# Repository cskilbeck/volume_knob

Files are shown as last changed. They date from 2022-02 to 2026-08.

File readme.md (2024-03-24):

# Tiny Little USB Knob

It sends HID or MIDI messages to the host device when you turn or click the knob.

Instructions for flashing new HID firmware are [here](https://skilbeck.com/tiny-usb-knob/tiny-usb-knob)

Instructions for flashing new MIDI firmware are [here](https://skilbeck.com/tiny-usb-knob/tiny-usb-midi-knob)

Configurator for the HID version is [here](https://hid.skilbeck.com)

Configurator for the MIDI version is [here](https://midi.skilbeck.com)

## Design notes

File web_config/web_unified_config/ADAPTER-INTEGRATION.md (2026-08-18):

# Adding the TRS MIDI adapter to the unified configurator

The `midi_adapter` project (`E:\dev\midi_adapter`) is a TRS-to-USB MIDI device that speaks
the same SysEx protocol as the Tiny MIDI Knob. It should appear in this configurator
alongside the knob and the HID keyboards rather than getting an app of its own.

Its firmware plan and the protocol details are in `midi_adapter/firmware/FIRMWARE-PLAN.md`;
the wire format is deliberately identical to the knob's.

## What the adapter is

TRS jack in, USB MIDI out. Three explicit modes — MIDI passthrough, expression pedal,
footswitch — chosen by the user, with **no auto-detection** (the reasoning is in the
firmware plan: an open footswitch is electrically identical to an empty jack, so detection
cannot be complete, and both non-MIDI modes need a calibration step from the user anyway).

Differences from the knob that matter here:

| | Knob | Adapter |
|---|---|---|
| model number | `0x3322` | `0x3323` |
| config device-type nibble | `0x0` | `0x1` |
| config length | 26 bytes | 32 bytes |
| SysEx `0x05` (bootloader) | supported | **not implemented** — the CH32V203 has no software path to its bootloader. Do not offer a firmware-update button for this device. |
| SysEx `0x06` (probe) | — | returns four raw ADC readings, for a future calibration UI |

## What is in the way

Three things in `Midi.js` are hardcoded to the knob:

1. `MIDI_MODEL_NUMBER_LOW/HIGH` — `on_device_id_response()` compares against them and
   returns early otherwise, so the adapter is currently invisible.
2. `CONFIG_LEN`, `config_map`, `default_config`, `flags`, `is_supported_config_version` —
   module-level, closed over by `config_from_bytes()` and `bytes_from_config()`.
3. `DeviceList.vue` renders `<MidiDevice>` for every MIDI device with no dispatch.

Plus: `on_midi_message()` routes only `0xB0` control change to devices. The adapter passes
through arbitrary MIDI, so the monitor needs a general hook.

## Plan

### 1. Device-type registry in `Midi.js`

A table keyed by model number holding what differs — model, config length, config map,
defaults, flags, and which component renders it. `on_device_id_response()` keeps checking
manufacturer and family, then *looks the model up* instead of comparing it, and stores the
entry as `device.type`. Unknown models are ignored and logged, as now.

`config_from_bytes()` and `bytes_from_config()` take the type as a parameter defaulting to
the knob, so existing call sites are untouched.

**The knob's tables deliberately stay in `Midi.js` for now** rather than moving to
per-device modules. This step is the only one that can break shipped hardware, so it is
kept to the smallest diff that works; `midi.default_config` and `midi.flags` continue to
export the knob's values so `MidiDevice.vue` needs no changes at all. That shim is
temporary — new code should read `device.type.*`.

**Verify the knob still enumerates and configures before going further.**

### 2. Adapter entry

Model `0x3323`, 32-byte config map. The map is already written and proven against real
hardware in `midi_adapter/web_test/index.html` — copy it from there rather than
re-deriving it from the C struct.

The struct is `__attribute__((packed))` and carries a `_Static_assert` on its size, because
without packing GCC puts a hole at offset 5 and the map silently decodes one byte out from
there on. A size assert cannot catch a *reordering*, so if `config.h` changes, this map
changes with it.

### 3. Dispatch in `DeviceList.vue`

Same shape as the existing HID dispatch: a name-to-component map, `:is` on the resolved
component, skip if unknown.

### 4. `MidiAdapterDevice.vue` — first cut, deliberately incomplete

- header: name, firmware version, connect toggle (patterns lifted from `MidiDevice.vue`)
- **mode selector** — passthrough / expression / switch — and save
- **MIDI monitor** — decoder already written in `midi_adapter/web_test/index.html`

Deferred: CC number and channel, ranges, direction, flags, thresholds, and the calibration
wizard built on SysEx `0x06`. The full 32-byte config still round-trips intact, because it
is read, one field is edited, and the whole thing is written back.

### 5. General MIDI hook

Route non-SysEx messages to `device.on_midi_in?.(data)` alongside the existing
`on_control_change` path. Additive; the knob is unaffected.

### 6. Dummy adapter

`make_dummy_midi_ports()` is already dependency-injected, so it takes a device type rather
than the knob's constants. Gives a "Demo TRS MIDI Adapter" for UI work with no hardware
attached, exactly as the demo knob does today.

## Later

- **Calibration wizard** on SysEx `0x06`: poll at ~20Hz, show live TIP and RING bars, ask
  the user to sweep the pedal. Whichever bar moves sets the wiper-on-ring flag and its
  extremes capture the input range. This is what replaces auto-detection, and it is better
  than firmware guessing precisely because the browser can ask a question and show a
  result.
- **Port naming.** The adapter's USB-MIDI jack descriptors carry no strings, so the host
  names its ports numerically. Either add string descriptors in firmware or lean on the
  existing localStorage rename in the device header.

## Two devices of the same name (done, 2026-08-15)

Two adapters both report their MIDI port as `midi_adapter`, and four things keyed on that
name: `device_from_input_port()` (which routes the monitor and every CC), the `'connected'`
branch of `on_state_change`, the reuse map in `init_devices()`, and `DeviceList.vue`'s
`:key`. The failure is quiet and confusing — one adapter's traffic draws on the other's
panel, and the second panel looks dead. Two knobs had the same fault; it was never
adapter-specific.

**Run-time identity is now `device.key`, the output port's id.** `device.input_id` is kept
separately because an input's id differs from its output's, and it is deliberately *not*
cleared on disconnect: it is the only way to recognise the port when it returns. The
reconnect path falls back to a name match restricted to devices with no port of that type
bound, which stays unambiguous among duplicates and preserves the old behaviour on a host
that renumbers ids across a replug.

**Persistent identity is the serial number**, which the adapter now appends to its identity
reply (`midi_adapter/firmware/FIRMWARE-PLAN.md` §4). Port ids are unique but not durable,
so per-unit labels in localStorage hang off the serial. Devices without one — the knob —
keep the old name-keyed label, so existing stored labels survive.

Demo port ids are qualified by name for the same reason: they were both hardcoded
`demo-midi-in` / `demo-midi-out` and would have collided under id-keying.

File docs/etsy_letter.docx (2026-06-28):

Here is your Tiny USB Volume Knob

Instructions

1. Plug it in using a USB cable.
2. Your computer should recognize it as ‘Tiny USB Knob’.
3. Twist the knob to change the audio volume.
4. Click the knob to mute/unmute your audio.

NOTE! READ THIS:

If it doesn’t work but flashes slowly after you’ve plugged it in, the USB connection failed – maybe the USB cable is a ‘Charger Only’ cable. Use a data-enabled cable! If you suspect the cable, try another device with it. If that also doesn’t work, try another cable.

Configuration

To change the HID codes that are sent when the knob is turned or clicked, point your Chrome browser at usbknob.com (https://hid.skilbeck.com) and click ‘Scan’ while your Tiny USB Knob is plugged in. Other browsers not supported, I’m afraid.

Discord

For help on Discord, search for the ‘Tiny USB Knob’ channel.

Advanced

To flash new firmware, click and hold the knob while you plug in the device. Once in flashing mode, you’ll have to either flash it with new firmware or unplug and plug it back in to get it back to normal mode.

`

IMPORTANT INSTRUCTIONS!

IMPORTANT INSTRUCTIONS!

IMPORTANT INSTRUCTIONS!

IMPORTANT INSTRUCTIONS!

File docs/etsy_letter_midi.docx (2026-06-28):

Here is your Tiny USB MIDI Knob

Instructions

1. Plug it in using a USB cable.
2. Your computer should recognize it as a device called ‘Tiny USB Knob’.
3. Turn and click the knob to send Continuous Control MIDI notifications.

Please read this!

If your Tiny USB MIDI Knob doesn’t work but flashes slowly after you’ve plugged it in, that means the USB connection failed. Maybe the USB cable is a ‘Charger Only’ cable without data lines. Use a data-enabled cable! If you suspect the cable, try another device with it. If that also doesn’t work, it’s time to find another cable.

Discord

To get help from me and other users on Discord, search for the ‘Tiny USB Knob’ channel

Configuration

If you want to change the CC values that are sent when the knob is turned or clicked, point your browser at usbknob.com (https://midi.skilbeck.com). It should pick up the device automatically,

But if it doesn’t try clicking ‘Scan’ while your Tiny USB MIDI Knob is plugged in. Safari is not supported.

Advanced users

If you want to flash new firmware, click and hold the knob while you plug in the device. Once in flashing mode, you’ll have to either flash it with new firmware or unplug and plug it back in to get it back to normal mode.

Important Instructions!

Important Instructions!

Important Instructions!

Important Instructions!

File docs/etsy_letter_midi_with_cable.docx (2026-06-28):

# Here is your Tiny USB MIDI Knob

Instructions

1. Plug it in using the supplied Micro-USB cable.
2. Your computer should recognize it as ‘Tiny USB Knob’.
3. Click and Twist the knob to send Continuous Control MIDI notifications.

Pro tip

If you want to change the CC values that are sent when the knob is turned or clicked, point your browser at usbknob.com. It should pick up the device automatically, but if it doesn’t try clicking ‘Scan’ while your Tiny USB MIDI Knob is plugged in. Safari is not supported.

Advanced users

If you want to flash new firmware, click and hold the knob while you plug in the device. Once in flashing mode, you’ll have to either flash it with new firmware or unplug and plug it back in to get it back to normal mode.

Support

Look for the “Tiny USB Knob” channel on Discord.

Important
Instructions

Important
Instructions

Important
Instructions

Important
Instructions

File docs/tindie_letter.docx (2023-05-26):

Hi,

Thanks so much for ordering a Tiny USB Volume Knob! I hope you get as much use out of it as I do.

Instructions

1. Plug it in using a Micro-USB cable
2. Your computer should recognize it as a device called ‘VOLUME KNOB’
3. Twist the knob to change the audio volume
4. Click the knob to mute your audio

NOTE

Please read this: If your Tiny USB Volume Knob doesn’t work but flashes slowly after you’ve plugged it in, that means the USB connection failed. This is because your USB cable is a ‘Charger Only’ cable without data lines. Please use a data-enabled cable! If you suspect the cable, try another device with it to test it. If that also doesn’t work, it’s time to find another cable.

Pro tip

If you want to change the direction (i.e. clockwise to decrease volume), triple click the knob. Triple click again to change it back.

Advanced users

If you want to flash new firmware, click and hold the knob down for over 5 seconds. Once the device is in flashing mode, you’ll have to either flash it with new firmware or unplug and plug it back in to get it back to normal mode.

And…

Small favour to ask – if you can bear it, would you mind awfully posting a Tweet about it? I don’t have a marketing budget (I don’t have any kind of budget at all, in fact), so getting the word out is kind of a challenge. Every mention helps! This QR code will get you started:

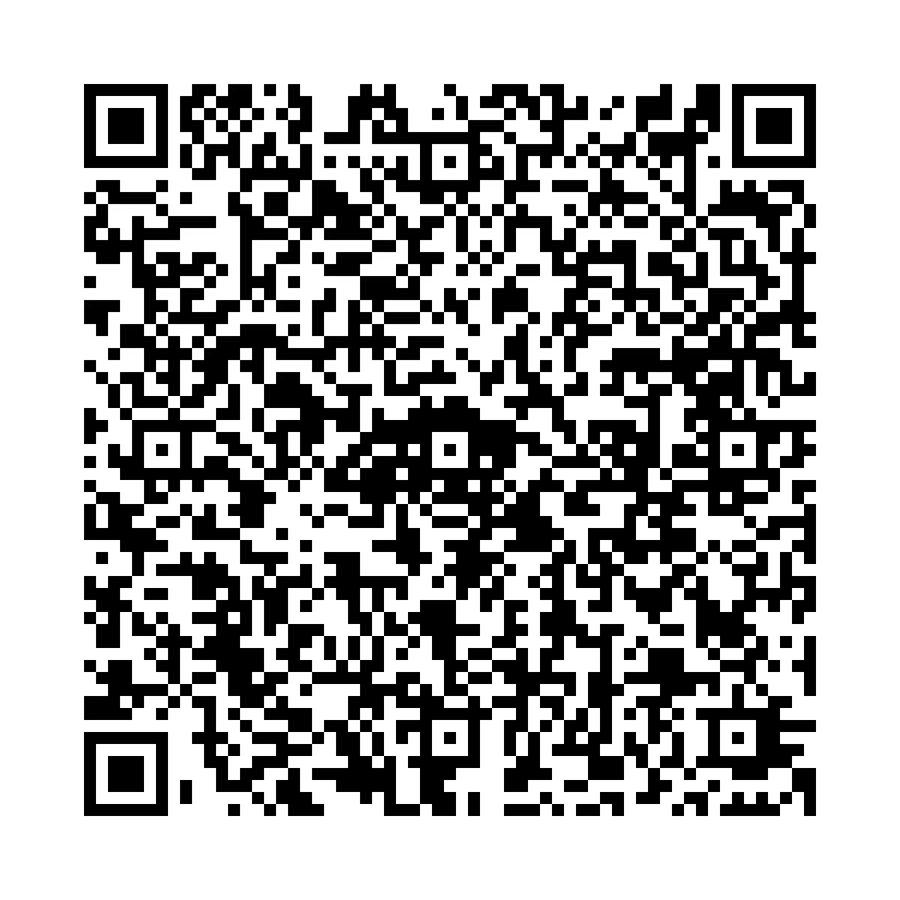
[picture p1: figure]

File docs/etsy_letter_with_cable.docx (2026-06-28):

Here is your Tiny USB Volume Knob

Instructions

1. Plug it in.
2. Your computer should recognize it as ‘Tiny USB Knob’.
3. Twist the knob to change the audio volume.
4. Click the knob to mute/unmute your audio.

Configuration

To change the HID codes that are sent when the knob is turned or clicked, point your Chrome browser at usbknob.com and click ‘Scan’ while your Tiny USB Knob is plugged in. Other browsers not supported, I’m afraid.

Discord Support

Seach for the Tiny USB Knob channel on Discord for help

Advanced

To put the device in ‘firmware flashing mode’, click and hold the knob while you plug in the device. Once in flashing mode, you’ll have to either flash it with new firmware or unplug and plug it back in to get it back to normal mode.

IMPORTANT
INSTRUCTIONS!

IMPORTANT
INSTRUCTIONS!

IMPORTANT
INSTRUCTIONS!

IMPORTANT
INSTRUCTIONS!

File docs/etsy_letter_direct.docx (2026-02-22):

Tiny USB Volume Knob

Instructions

1. Plug it in
2. Your computer should recognize it as a device called ‘Tiny USB Knob’.
3. Twist the knob to change the audio volume.
4. Click the knob to mute/unmute your audio.

Get Help on Discord

Get help on Discord! Search for the “Tiny USB Knob” channel.

Configuration

To change the keys that are sent when the knob is turned or clicked, point your browser (NOT Safari!) at hid.skilbeck.com and click ‘Scan’ while your Tiny USB Knob is plugged in.

Advanced Users

To flash new firmware, click and hold the knob while you plug in the device. Once in flashing mode, you’ll have to either flash it with new firmware or unplug and plug it back in to get it back to normal mode.

Important
Instructions!

Important
Instructions!

Important
Instructions!

Important
Instructions!

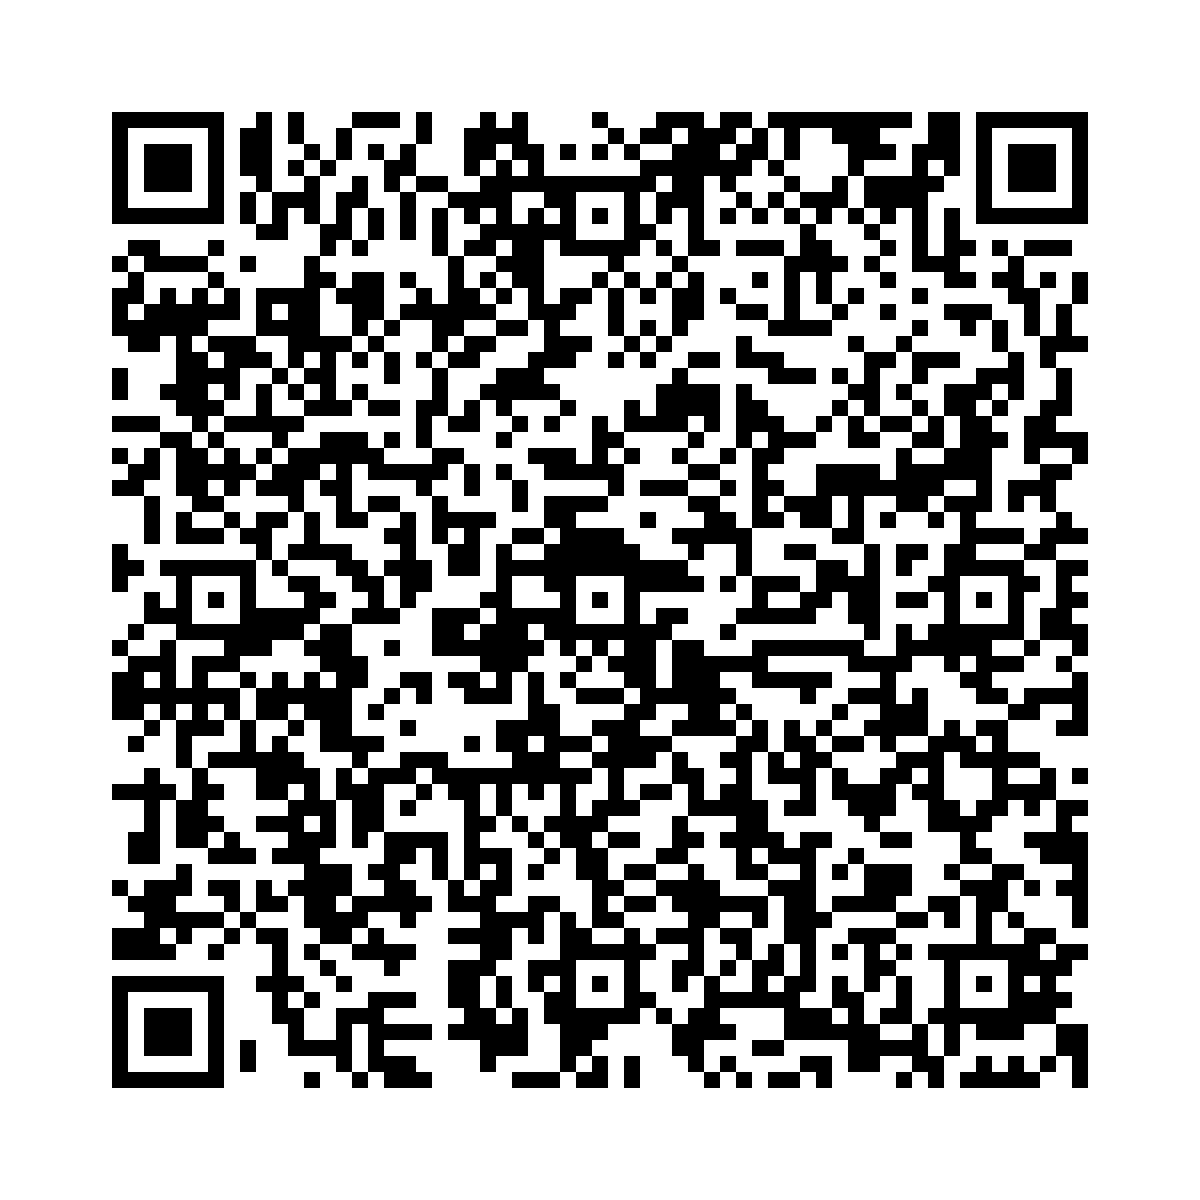
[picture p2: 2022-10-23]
images/qr_etsy.png

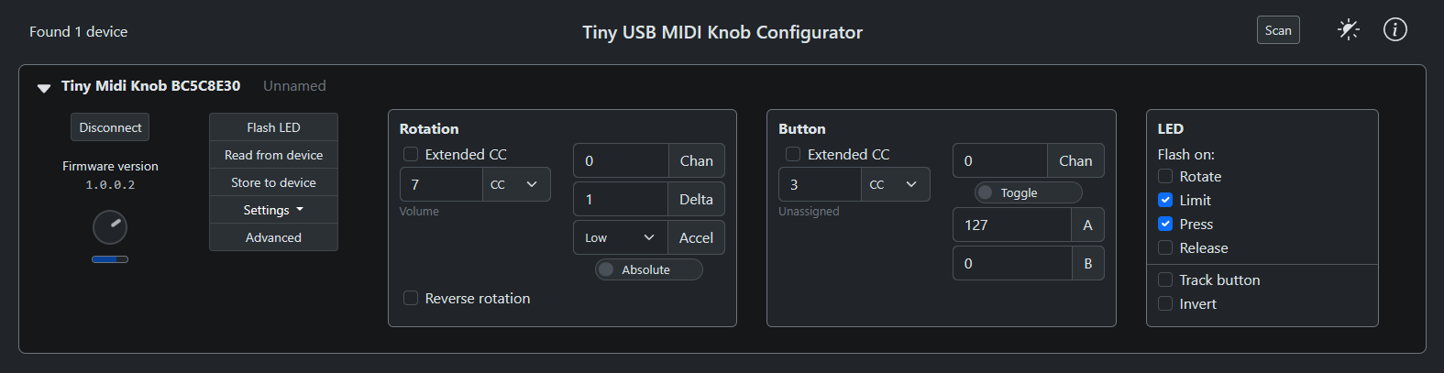
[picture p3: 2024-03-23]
images/midi_configurator_1.png

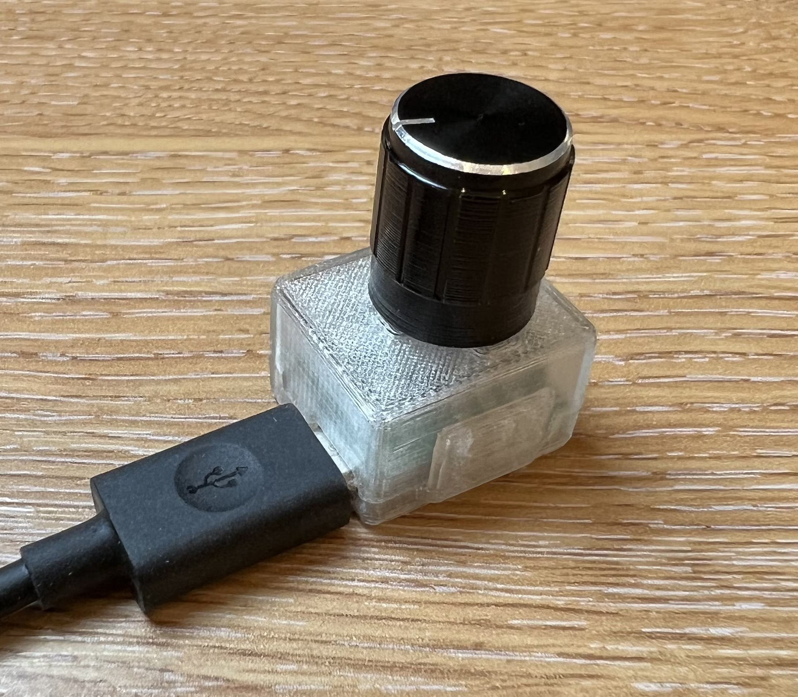
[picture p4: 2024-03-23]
images/tiny_usb_device.jpg

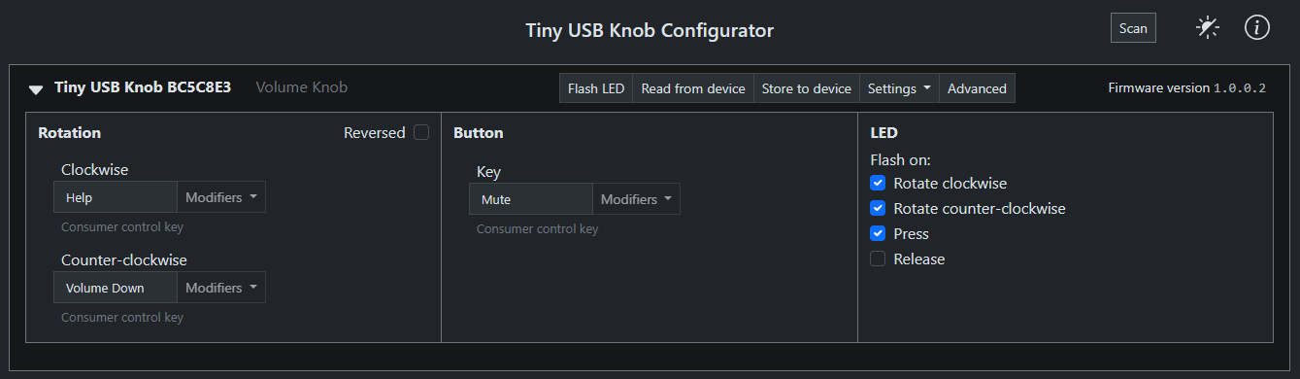
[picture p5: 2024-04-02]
images/hid_configurator_2.png

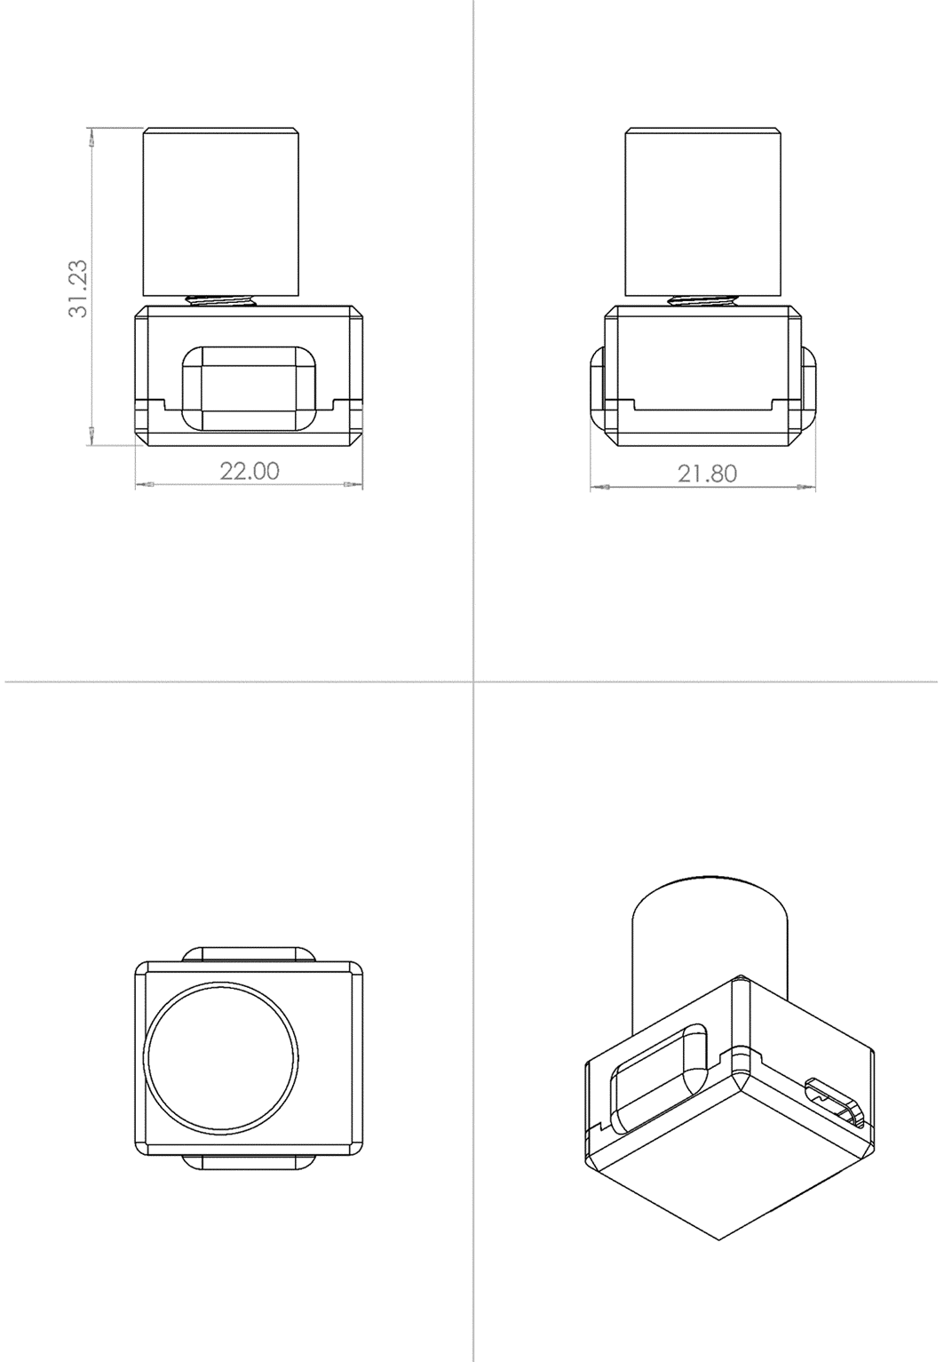
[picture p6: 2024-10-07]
images/dimensions.png

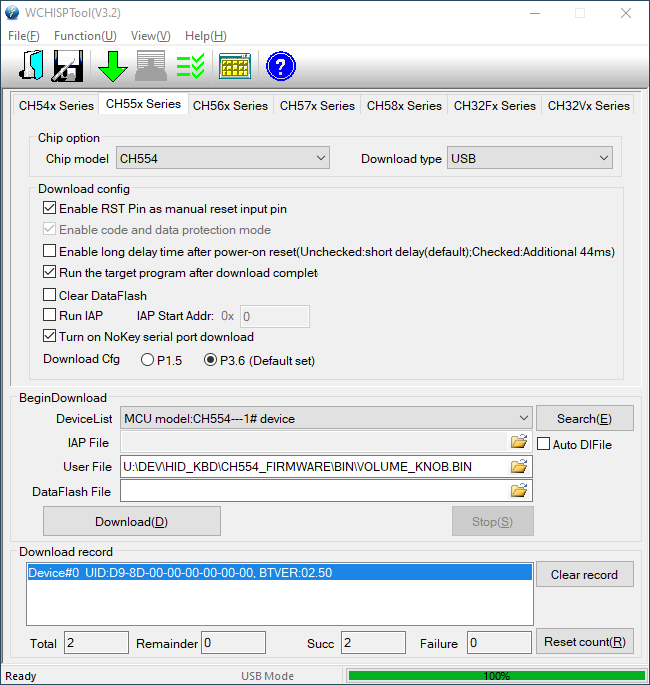
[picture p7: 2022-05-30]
images/wchisp_1.png

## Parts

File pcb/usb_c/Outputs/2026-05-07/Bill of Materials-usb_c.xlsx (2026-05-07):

Designator | Quantity | Comment | Description | Footprint | JLCPCB Part #
C6, C7 | 2 | 1uF | MLCC | MLCC_0603 | C29936
D1 | 1 | 20mA | LED | SMT_LED_0603 | C205445
D6, D7, D8 | 3 | TVS_DIODE | TVS Diode | TVS_DIODE | C151980
F2 | 1 | 1A | Resettable fuse | FUSE 0603_1608 0.5MM | C210357
R1 | 1 | 680r | Resistor | SMT_RES_0603 | C23228
R2, R3 | 2 | 5.1k | Resistor | SMT_RES_0603 | C25804
R6, R7, R8 | 3 | 220r | Resistor | SMT_RES_0603 | C27592
R10 | 1 | 10k | Resistor | SMT_RES_0603 | C25804
U1 | 1 | CH554E | CH554E | MSOP10 | C111293
USB | 1 | USB_C_16_PIN | USB Receptacle TYPE-C 16PIN 2MD | USB_C_16PIN | C2765186

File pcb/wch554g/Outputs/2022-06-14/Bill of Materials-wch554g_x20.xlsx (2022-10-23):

Designator | Quantity | Comment | Description | Footprint | JLCPCB Part #
C6, C7 | 40 | 1uF | MLCC | MLCC 0603 | C105524
C8, C9, C10 | 60 | 6.8nF | MLCC | MLCC 0603 | C1631
D5 | 20 | 20mA | LED | SMT LED 0603 | C138545
D6, D7, D8 | 60 | TVS_DIODE | TVS Diode | SODFL 98x40 2 pin | C384848
F2 | 20 | 1A | FUSE | FUSE_0805 | C70061
MCU2 | 20 | CH554G | CH554G SOP16 MCU | SOP16 x1.27 | C114295
R6, R7, R8 | 60 | 68r | Resistor | 0603 SMT Resistor | C27592
R9 | 20 | 680r | Resistor | 0603 SMT Resistor | C23228
R10 | 20 | 10k | Resistor | 0603 SMT Resistor | C25804
USB | 20 | USB Micro | USB Receptacle | USB Micro B Receptacle | C397452

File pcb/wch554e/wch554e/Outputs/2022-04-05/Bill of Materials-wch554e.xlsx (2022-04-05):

Designator | Quantity | Comment | Description | Footprint | JLCPCB Part #
U1 | 1 |  | CH554E | MSOP10 3x3 x 0.5 | C111293
F1 | 1 | 1A | FUSE | FUSE_0805 | C70061
D4 | 1 |  | LED | SMT LED 0603 | C434424
C1, C2 | 2 | 1uF | MLCC | MLCC 0603 | C105524
C3, C4, C5 | 3 | 10nF | MLCC | MLCC 0603 | C519509
R1, R2, R3 | 3 | 120r | Resistor | 0603 SMT Resistor | C22787
R4 | 1 | 10k | Resistor | 0603 SMT Resistor | C25804
R5 | 1 | 680r | Resistor | 0603 SMT Resistor | C23228
D1, D2, D3 | 3 |  | TVS Diode | SODFL 98x40 2 pin | C384848
J1 | 1 |  | USB Receptacle | USB Micro B Receptacle | C397452

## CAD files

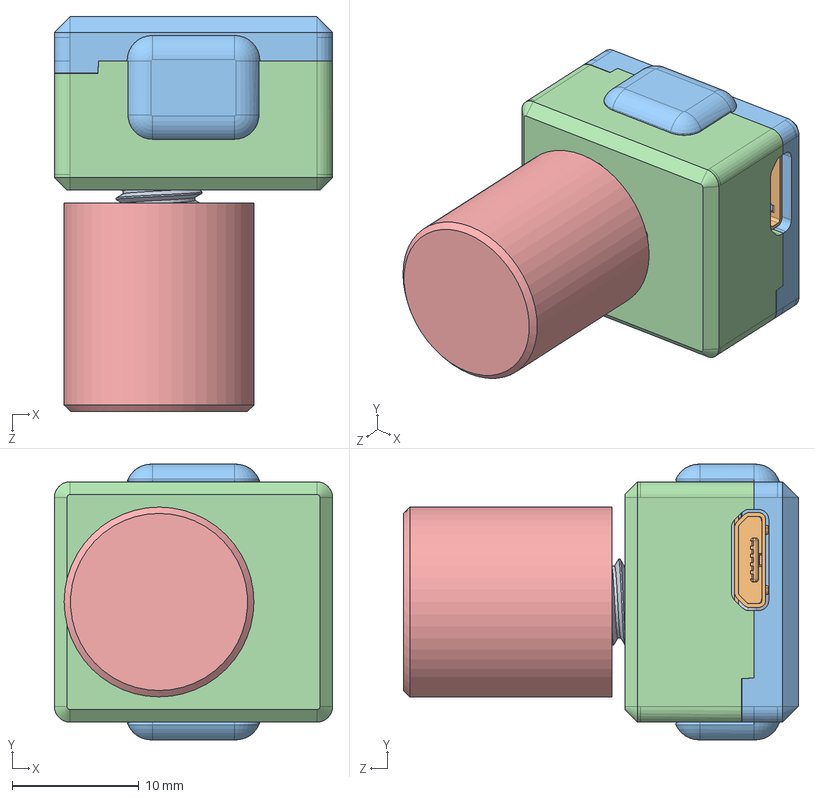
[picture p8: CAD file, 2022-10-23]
enclosure_ch554e_80/enclosure.SLDASM
22.0 x 21.8 x 31.2 mm
pcb
usb_socket
lower
upper
knob

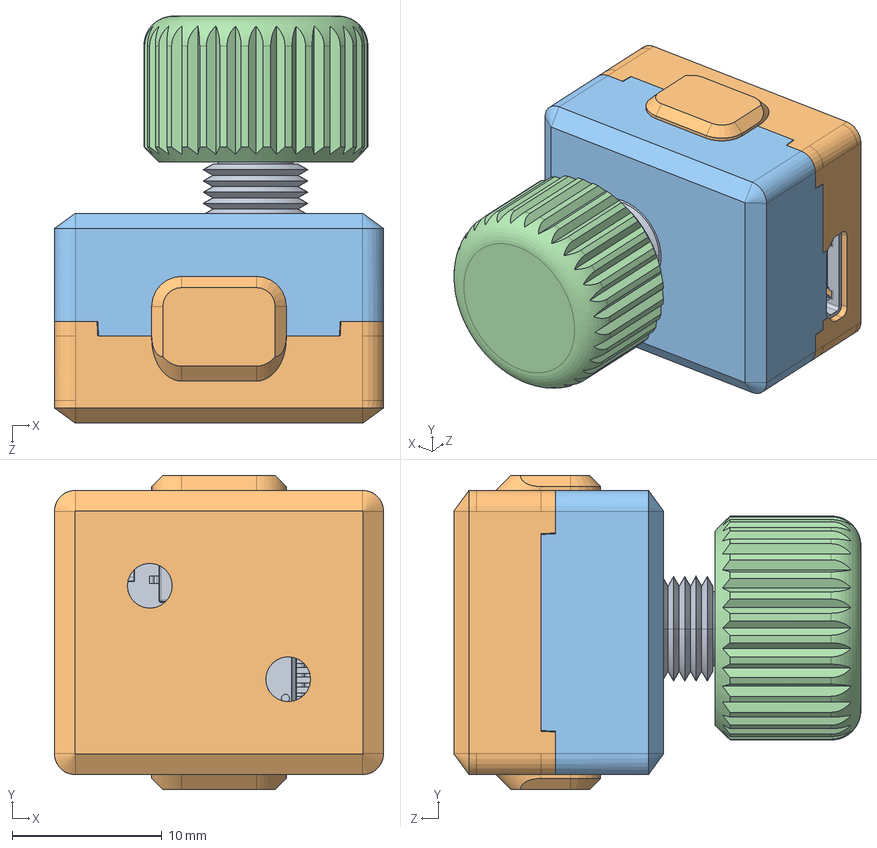
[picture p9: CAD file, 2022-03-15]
enclosures/enclosure16x19/enclosure2.SLDASM
22.0 x 21.0 x 27.2 mm
pcb
lower
upper
knob

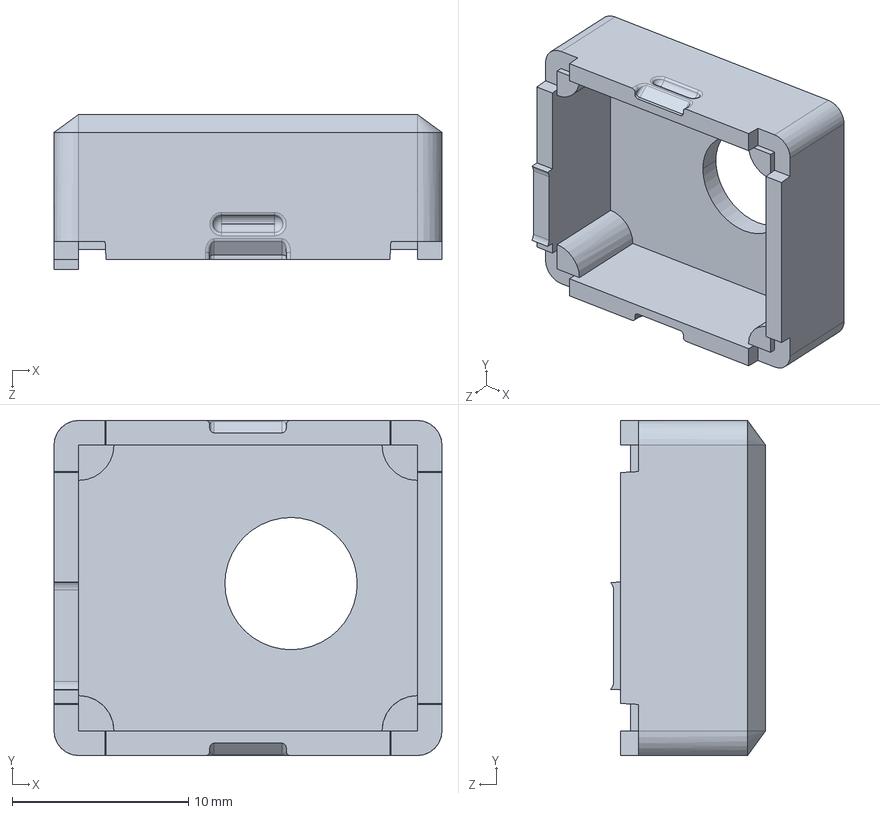
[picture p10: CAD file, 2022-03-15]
enclosures/enclosure16x19/upper.SLDPRT
22.0 x 19.0 x 8.76 mm

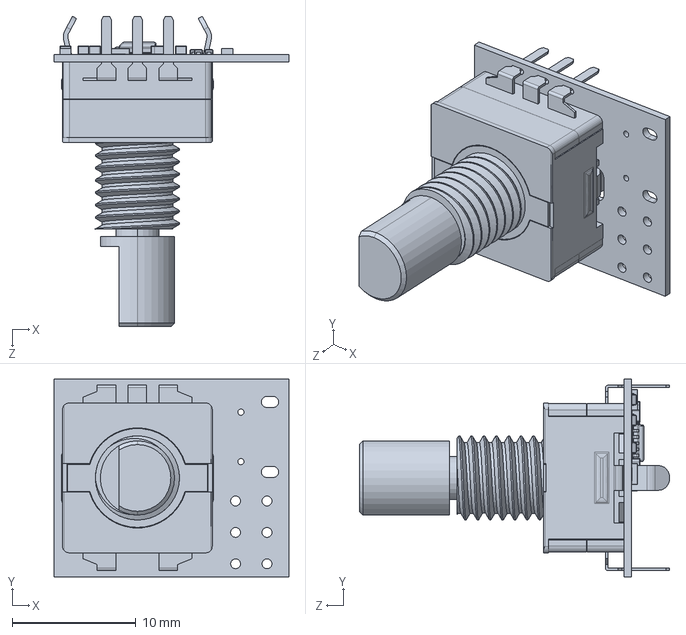
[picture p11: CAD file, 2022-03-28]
enclosures/enclosure_ch554e/pcb_ch554e.SLDPRT
19.0 x 16.0 x 25.1 mm

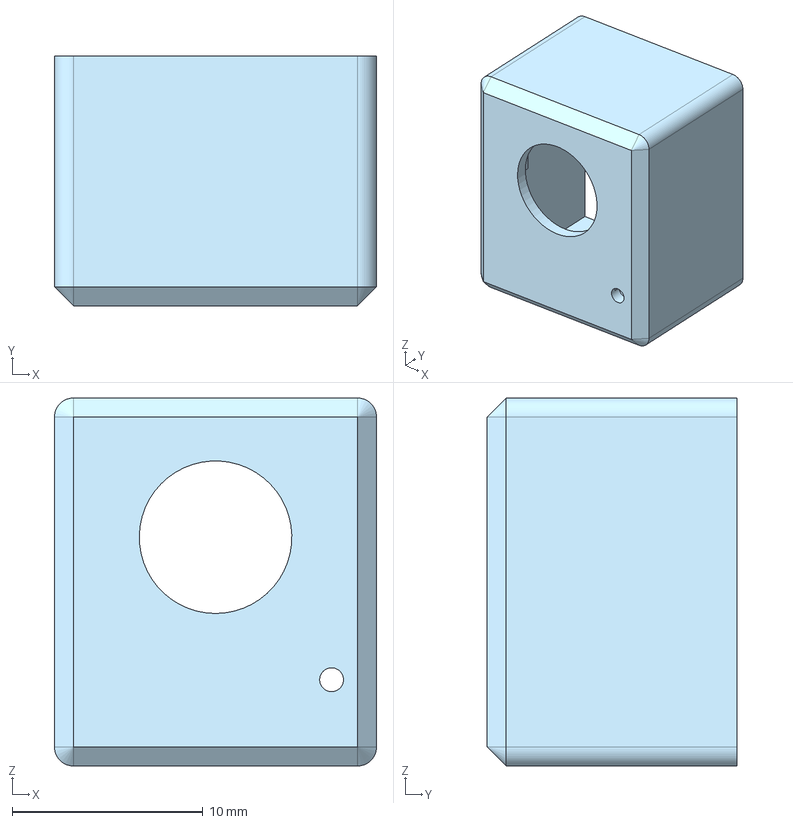
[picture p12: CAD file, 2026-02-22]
enclosures/VK_D1.step
16.9 x 13.1 x 19.3 mm

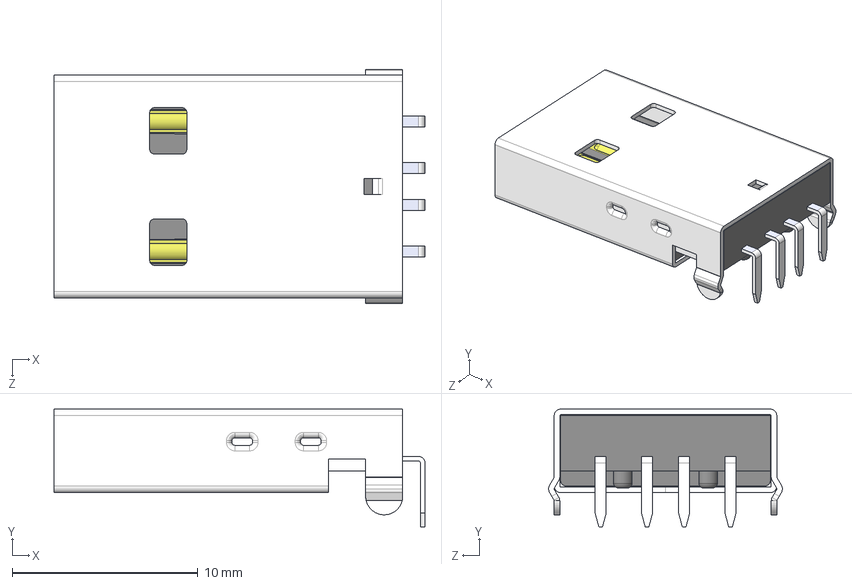
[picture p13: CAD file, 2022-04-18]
pcb/CUI_DEVICES_UP2-AH-1-TH.step
20.0 x 6.35 x 12.6 mm

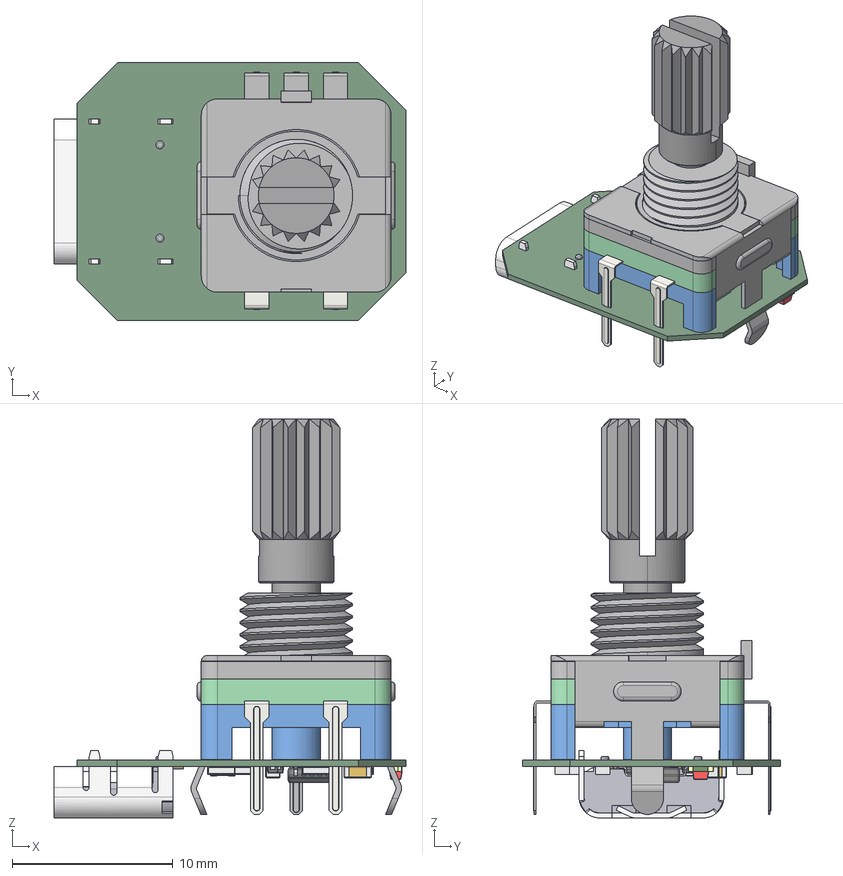
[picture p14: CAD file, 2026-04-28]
pcb/usb_c/Outputs/2026-04-28/usb_c.step
21.9 x 16.0 x 24.8 mm
FUSE 0603_1608 0.5MM
Mid_Body x 7
Mark x 7
tongue
shield
contact_001
contact_002
contact_003
contact_004
contact_court_001
contact_court_002
contact_court_003
contact_court_004
contact_005
contact_006
contact_007
contact_008
contact_court_005
contact_court_006
contact_court_007
contact_court_008
pin_001
pin_002
pin_003
pin_004
pin_005
pin_006
pin_007
pin_008
pin_009
pin_010
pin_011
pin_012
pin_013
pin_014
pin_015
pin_016
Leader x 10
EC11_Rotary_Encoder_Switched
lead x 6
0603 Chip SMD LED (1.6x0.8mm)_coloured

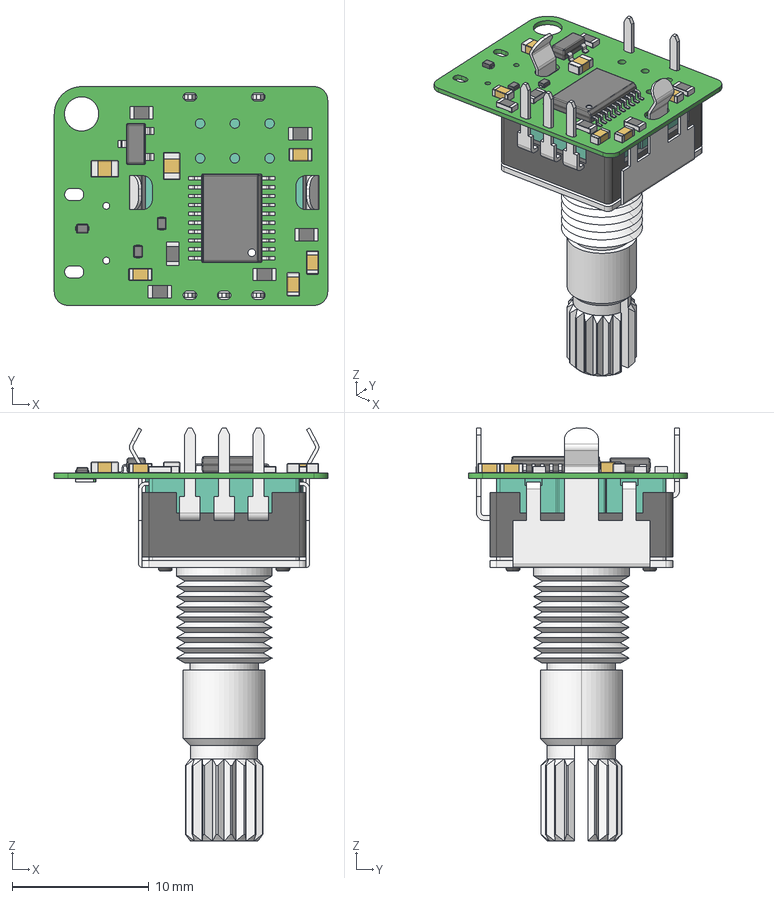
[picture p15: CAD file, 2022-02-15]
pcb/volume_knob/Outputs/2022-02-15/volume_knob.step
20.0 x 16.0 x 30.2 mm
scaled
Open_CASCADE_STEP_translator_6.8_2.1.1 x 3
lead x 6
Mid_Body x 6
Open_CASCADE_STEP_translator_6.8_12.2.1 x 12
Mark x 6
Open_CASCADE_STEP_translator_6.8_14.1
Open_CASCADE_STEP_translator_6.8_14.2.1 x 5
Leader x 23
Open_CASCADE_STEP_translator_6.8_14.1.1 x 4
Open_CASCADE_STEP_translator_6.8_14.1.2 x 4
Open_CASCADE_STEP_translator_6.8_28.1.1 x 2
Open_CASCADE_STEP_translator_6.8_28.1.2 x 2
Open_CASCADE_STEP_translator_6.8_28.2.1 x 2
Open_CASCADE_STEP_translator_6.8_1.1.1

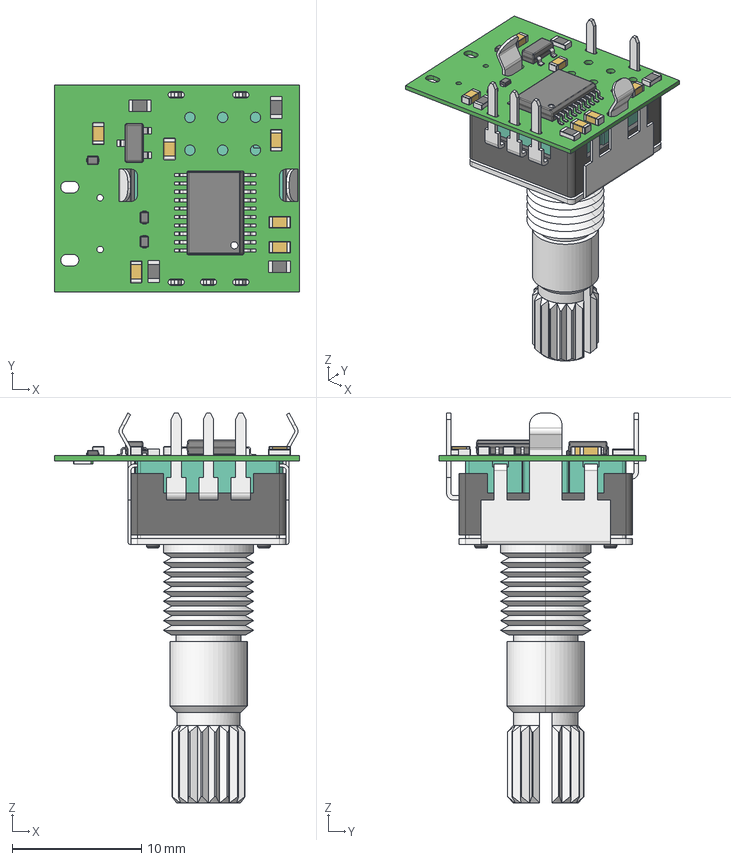
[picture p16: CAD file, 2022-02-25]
pcb/volume_knob/Outputs/2022-02-25/volume_knob.step
19.0 x 16.0 x 30.2 mm
scaled
Open_CASCADE_STEP_translator_6.8_2.1.1 x 3
lead x 6
Mid_Body x 4
Open_CASCADE_STEP_translator_6.8_12.2.1 x 8
Mark x 4
Open_CASCADE_STEP_translator_6.8_14.1
Open_CASCADE_STEP_translator_6.8_14.2.1 x 7
Leader x 23
Open_CASCADE_STEP_translator_6.8_14.1.1 x 6
Open_CASCADE_STEP_translator_6.8_14.1.2 x 6
Open_CASCADE_STEP_translator_6.8_1.1.1

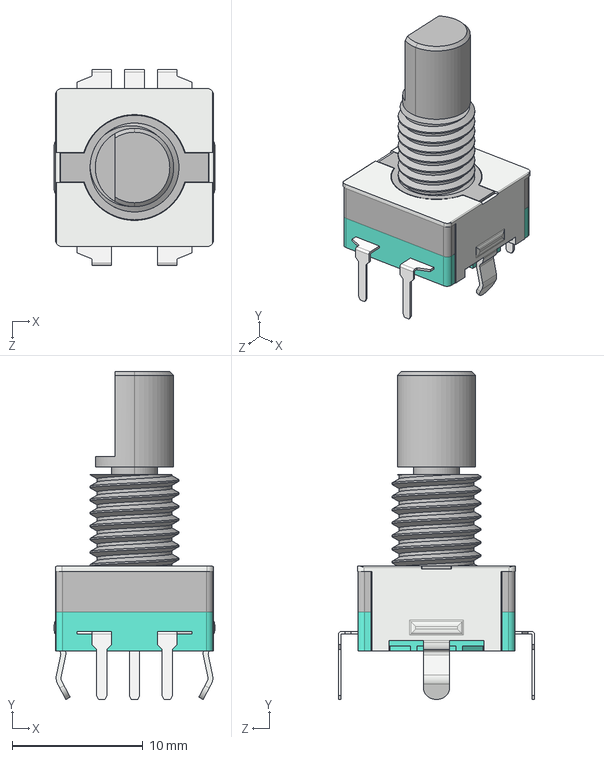
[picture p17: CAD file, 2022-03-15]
pcb/wch554e/wch554e/Models/rotary_encoder.STEP
12.3 x 25.1 x 15.0 mm

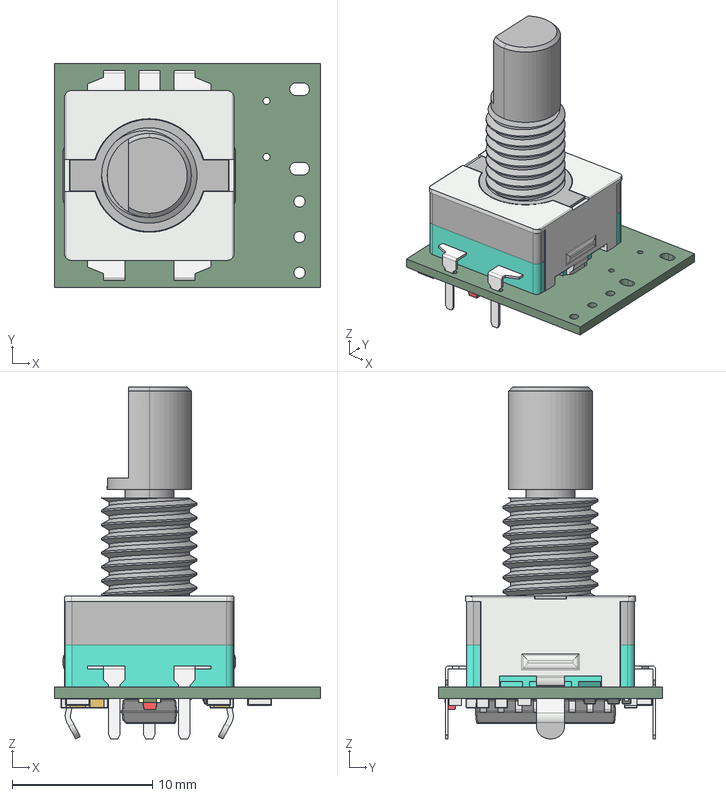
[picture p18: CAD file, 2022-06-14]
pcb/wch554g/Outputs/2022-06-14/wch554g.step
19.0 x 16.0 x 25.1 mm
Open_CASCADE_STEP_translator_6.8_2.1
Open_CASCADE_STEP_translator_6.8_2.2.1
Leader x 16
rotary_encoder
Mid_Body x 5
Open_CASCADE_STEP_translator_6.8_12.2.1 x 10
Mark x 5
Open_CASCADE_STEP_translator_6.8_2.1.1 x 3
lead x 6
0603_Chip_SMD_LED_(1.6x0.8mm)_coloured
Open_CASCADE_STEP_translator_6.8_14.1.1 x 5
Open_CASCADE_STEP_translator_6.8_14.1.2 x 5
Open_CASCADE_STEP_translator_6.8_14.2.1 x 5

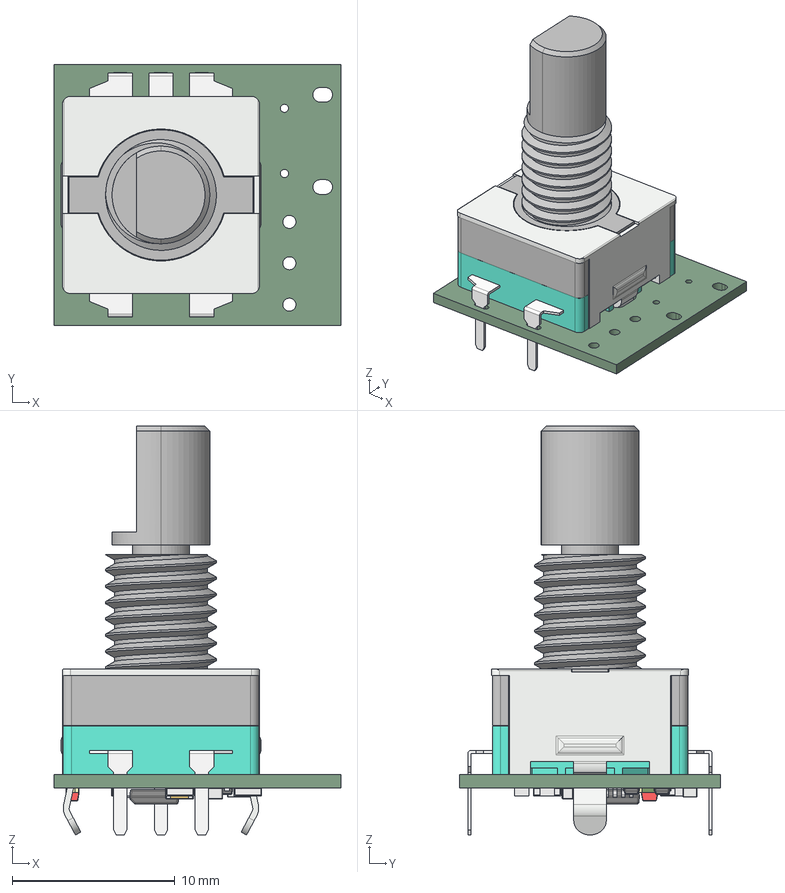
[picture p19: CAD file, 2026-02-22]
pcb/wch554g/Outputs/2025-04-25_V2/wch554g.step
17.6 x 16.0 x 25.1 mm
Mid_Body x 5
Open_CASCADE_STEP_translator_6.8_12.2.1 x 11
Mark x 5
0603_Chip_SMD_LED_(1.6x0.8mm)_coloured
Open_CASCADE_STEP_translator_6.8_12.1
Leader x 10
rotary_encoder
FUSE_0603_1608_0.5MM
Open_CASCADE_STEP_translator_6.8_2.1.1 x 3
lead x 6
Open_CASCADE_STEP_translator_6.8_14.1.1 x 2
Open_CASCADE_STEP_translator_6.8_14.1.2 x 2
Open_CASCADE_STEP_translator_6.8_14.2.1 x 2

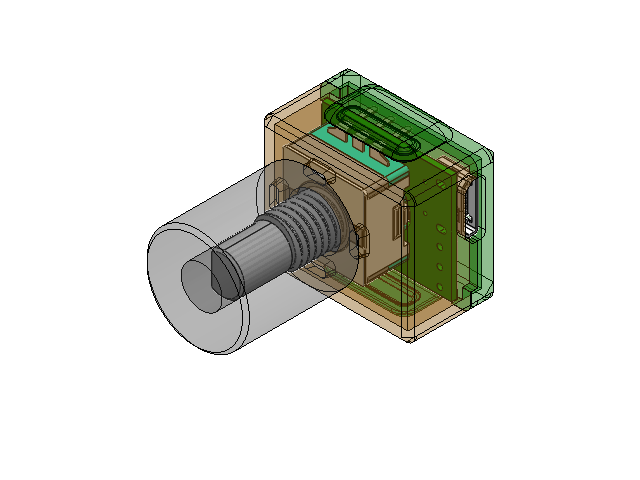
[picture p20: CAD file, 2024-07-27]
enclosures/enclosure_ch554e_80/enclosure.SLDASM
pcb
usb_socket
lower
upper
knob

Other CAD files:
enclosures/enclosure_ch554e_80/pcb.SLDPRT
enclosures/enclosure_V2/knob.SLDPRT
pcb/usb_c/Outputs/2026-05-07/usb_c.step
pcb/wch554e/wch554e/Outputs/2022-04-05/wch554e.step
pcb/wch554g/models/rotary_encoder_1.step.SLDPRT
enclosures/TUVK_Enclosure.step
enclosures/VK_D1.3mf
enclosures/VK_D2.step
enclosures/enclosure/473461001.sldprt
enclosures/enclosure/bottom.SLDPRT
enclosures/enclosure/knob.SLDPRT
enclosures/enclosure/knob.STEP
enclosures/enclosure/lower.STEP
enclosures/enclosure/top.SLDPRT
enclosures/enclosure/upper.STEP
enclosures/enclosure/volume_knob.SLDASM
enclosures/enclosure16x19/encoder.SLDPRT
enclosures/enclosure16x19/encoder2.SLDPRT
enclosures/enclosure16x19/knob.SLDPRT
enclosures/enclosure16x19/lower.SLDPRT
enclosures/enclosure16x19/usb_receptacle.sldprt
enclosures/enclosure_V2/PCB_V2.step
enclosures/enclosure_V2/enclosure_V2.SLDDRW
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

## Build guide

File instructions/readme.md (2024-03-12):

## Tiny USB Midi Knob - Instructions for flashing new firmware

#### 1.  Install <a href="https://www.wch-ic.com/downloads/WCHISPTool_Setup_exe.html" target="_blank">WCHISPTool</a>

#### 2. Download [tiny_midi_knob_1.0.bin](tiny_midi_knob_1.0.bin)

#### 3. Put the device in Firmware Flashing Mode
- If you are converting a HID Volume Knob (i.e. it has never been flashed with Midi Firmware):
    - Press and hold the button for more than 5 seconds
- If it's already a Midi Knob (i.e. you bought a Midi Knob or you've already flashed it with the Midi Firmware at least once):
    - Activate Firmware Flashing Mode using the 'Advanced' button in the [Web Config UI](https://midi.skilbeck.com)
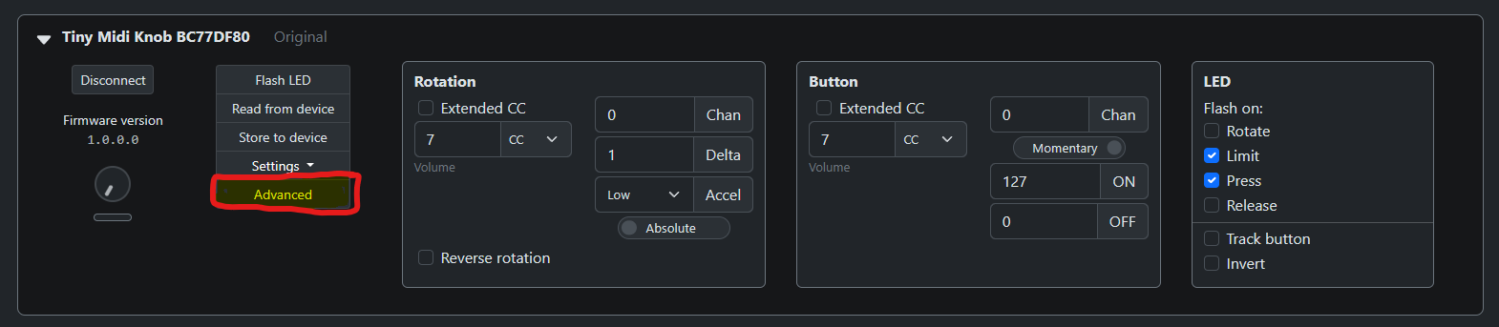
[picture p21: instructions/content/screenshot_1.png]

    - When the device goes into Firmware Flashing Mode you should see the LED flicker briefly.

#### 4. Run WCHISPTool
- It should look something like this
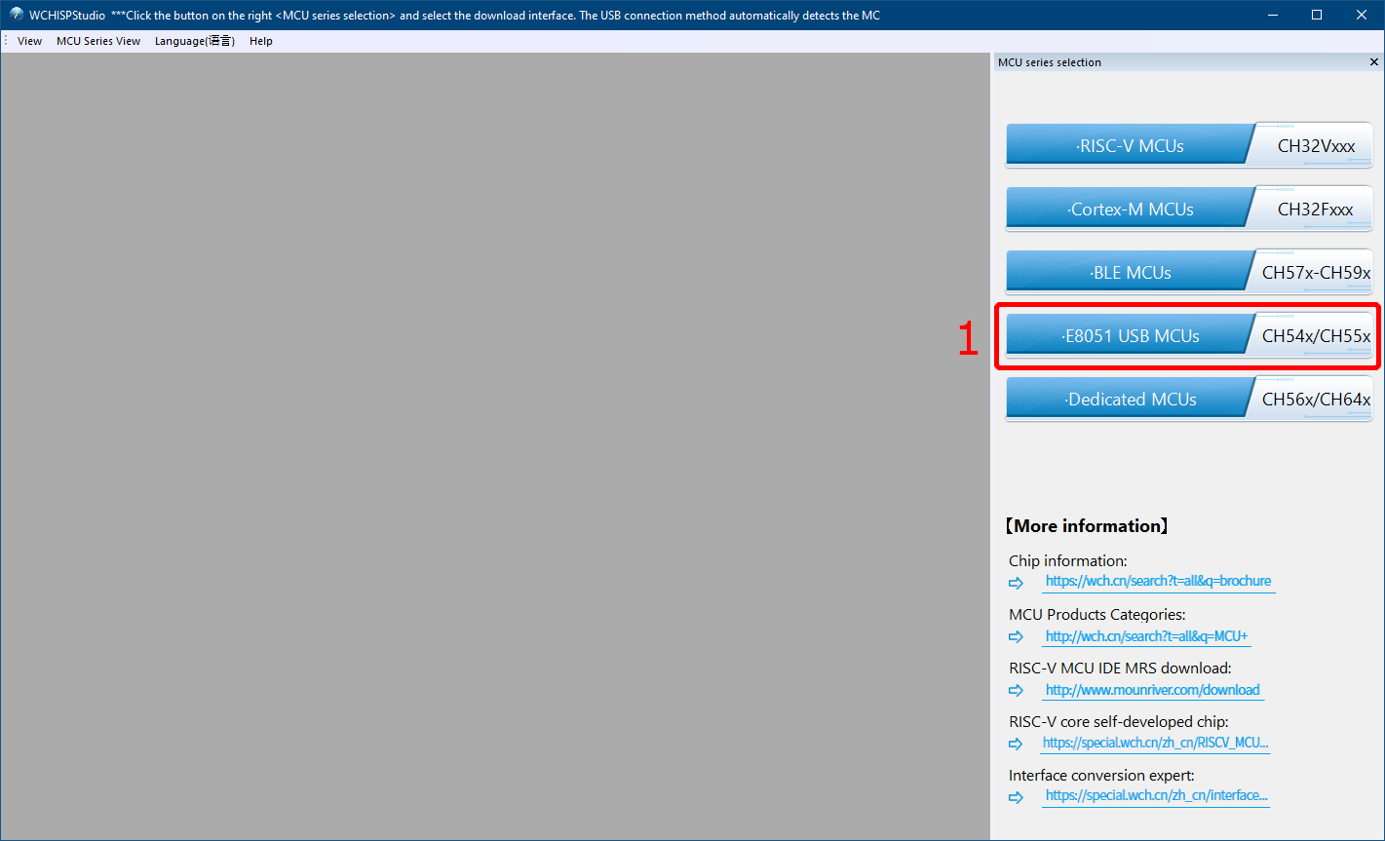
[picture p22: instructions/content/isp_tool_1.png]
isp_tool_1

- Click 'E8051 USB MCUs' to bring up the correct page
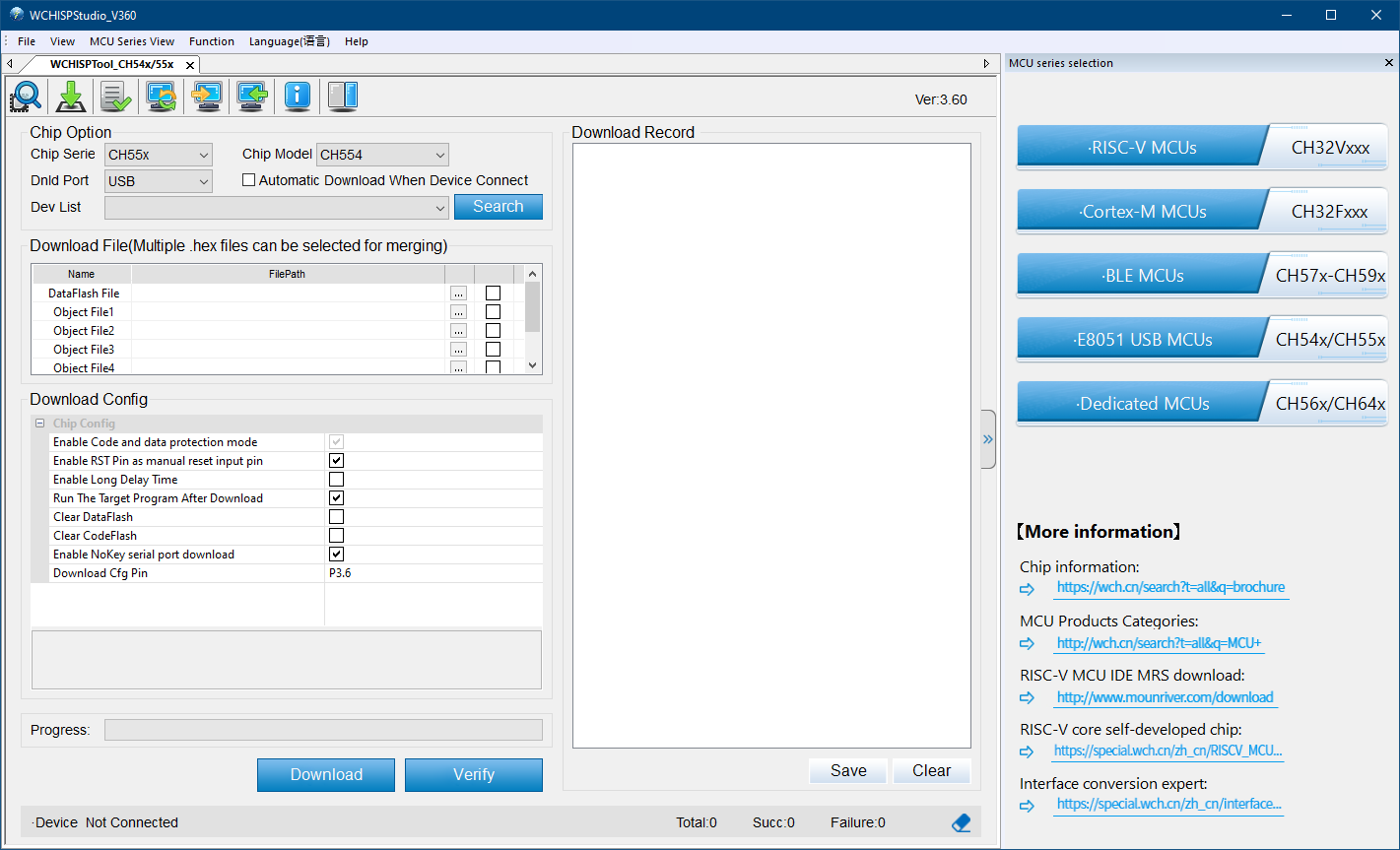
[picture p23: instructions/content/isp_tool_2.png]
isp_tool_2

- Your device should show up in the 'Dev List'. If it doesn't try clicking 'Search'
- Click the browse button for 'Object File 1' and select `tiny_midi_knob_1.0.bin` that you downloaded in step 3.
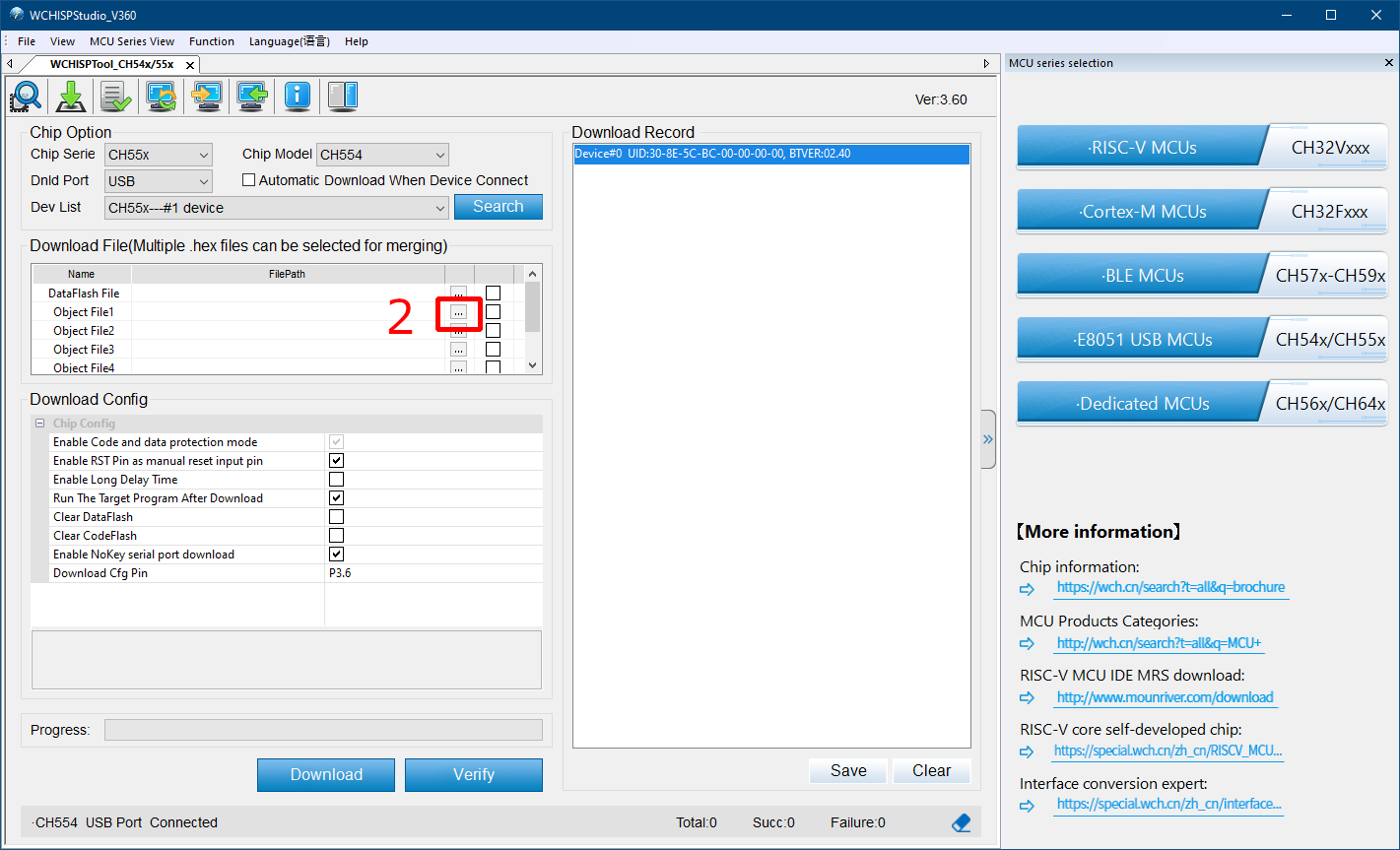
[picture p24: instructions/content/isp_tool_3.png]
isp_tool_3

- Make sure 'Run The Target Program After Download' is checked
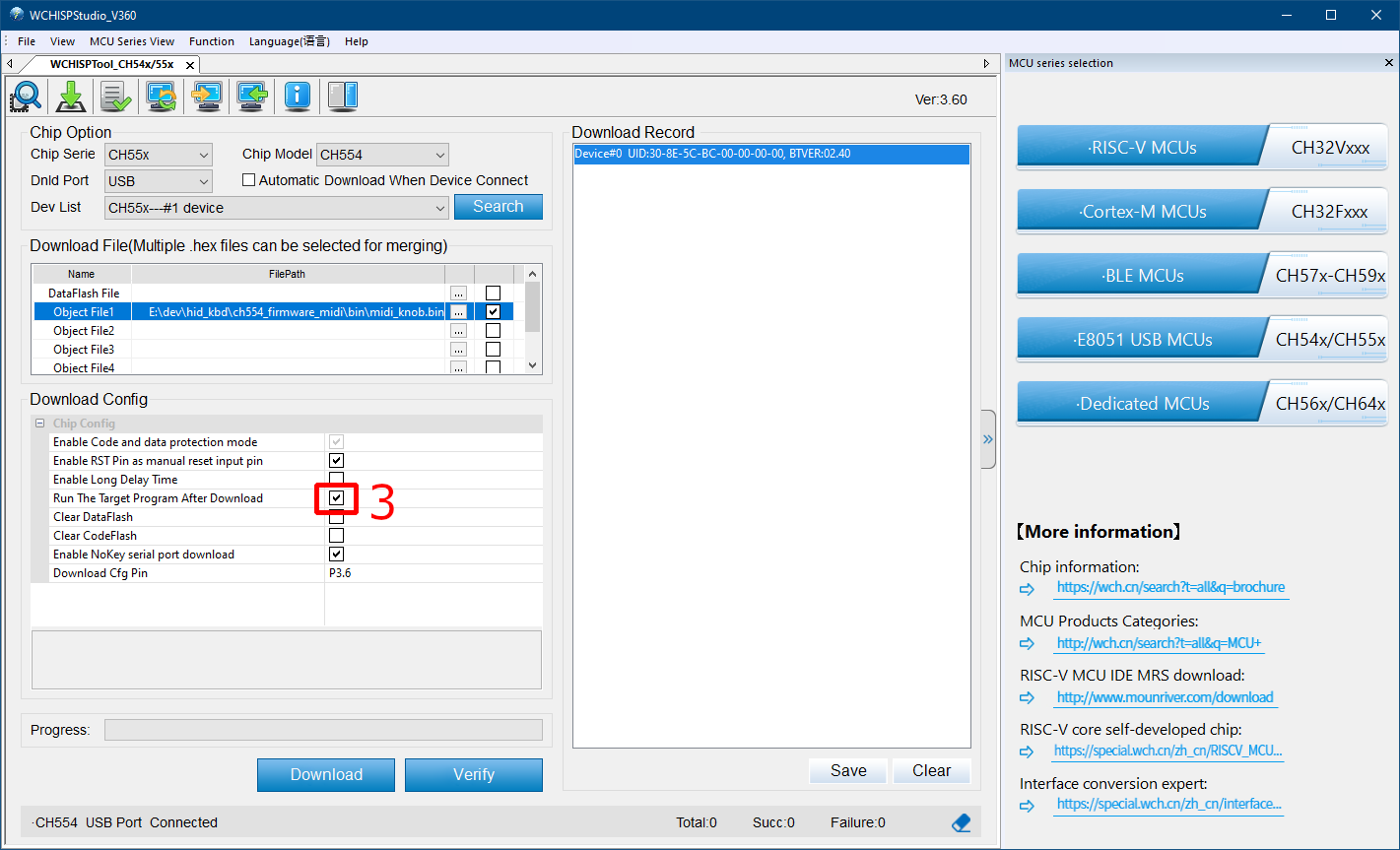
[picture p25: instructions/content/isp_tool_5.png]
isp_tool_5

- Click 'Download' to flash the device
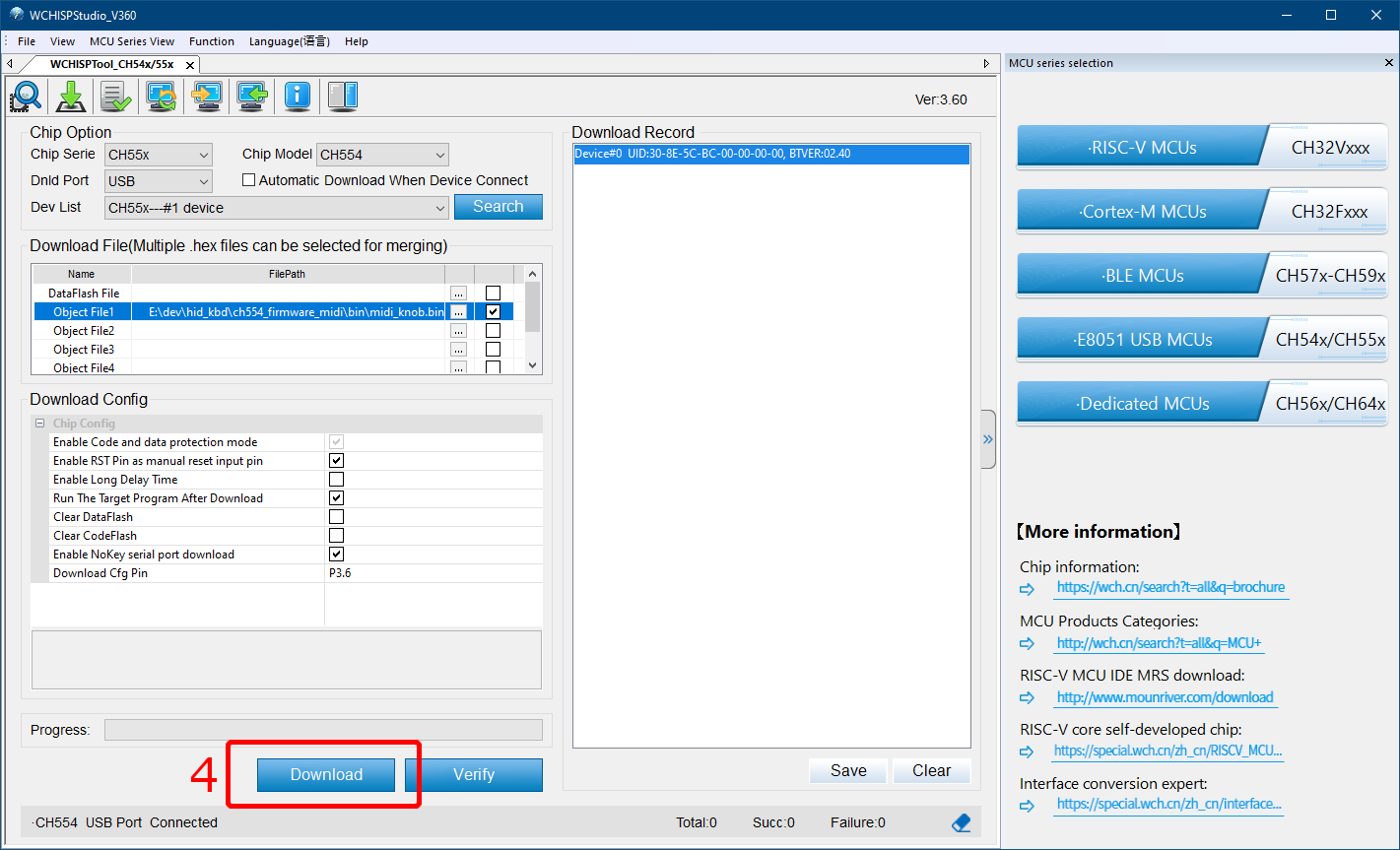
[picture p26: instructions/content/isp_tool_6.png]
isp_tool_6

- Inspect the 'Download Record' for any errors
- Test the device - you will need to refresh the [Web Config UI](https://midi.skilbeck.com) page or click 'Scan'.

[screenshot_1]:./content/screenshot_1.png

[isp_tool_1]:./content/isp_tool_1.png
[isp_tool_2]:./content/isp_tool_2.png
[isp_tool_3]:./content/isp_tool_3.png
[isp_tool_4]:./content/isp_tool_4.png
[isp_tool_5]:./content/isp_tool_5.png
[isp_tool_6]:./content/isp_tool_6.png

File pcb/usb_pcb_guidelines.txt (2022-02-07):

The 1k5 pull-up resistor should be on the connector side of the series resistor

USB terminating (series) resistors should be close to the chip, within 200 mils, not close to the connector.

1k5 pull-up should be controllable by the MCU, as it could take more time to boot the STM32 firmware than the host tolerates for enumeration

Stubs should be avoided. The trace from the differential pair to the 1.5k pullup forms a stub, even if it is very small. The resistor pad could be just in-line with the trace without stub. Smaller size resistors would have smaller pads. The stub length is well within recommendations.

It is not suggested to connect USB shield directly to ground plane and shorting to USB GND, but via capacitor.

VBUS and/or GND are sometimes filtered with ferrite beads.

Don't put more than the allowed 10uF capacitance on VBUS

Don't draw more than the allowed 100mA until MCU has completed enumeration to request more current from host, and the host has allowed it

USB DP/DN is a differential pair whose impedance should be 90 ohms

Avoid traces that run in parallel near USB traces. There should be 20 mil gap to non-periodic low speed signals, or 50 mil gap to clock signals.

If you don't pass EMI testing, you might need to add a common-mode choke near the connector. The ESD protection should be located between connector and common-mode choke.

Match DP/DM trace lengths to within 150 mils.

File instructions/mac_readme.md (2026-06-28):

We will use a small free tool called **wchisp**. There's no app to click on, you'll type a few commands into a program called **Terminal**. Don't worry if you've never done this before: every command below can be **copied and pasted** into the Terminal.

> These instructions are for **Apple Silicon Macs** (any Mac with an M1, M2, M3 or M4 chip - that's every Mac sold since late 2020). To check: click the  menu (top-left) → **About This Mac**. If it says "Chip: Apple M…", you're good to go.

The first time takes about 5 minutes (mostly the one-time setup in Step 1). After that, re-flashing only takes a minute.

---

### Before you start: how to open Terminal

Terminal is an app that comes with every Mac. To open it:

1. Press **Cmd (⌘) + Space** to open Spotlight search.
2. Type **Terminal** and press **Return**.
3. A window with plain text and a blinking cursor will appear. This is where you'll paste commands.

**How to run a command:** click once inside the Terminal window, paste the command (**Cmd + V**), then press **Return**. That's it. When a command finishes, the blinking cursor comes back and you can paste the next one.

> Tip: Terminal won't show anything when you type or paste a password - no dots, no stars. That's normal. Just type it and press Return.

---

### 1. Download and unlock the flashing tool (one-time setup)

You only ever have to do this **once**. After it's set up, skip straight to Step 2 next time. Nothing here gets "installed" - it's just a single small file that lives in your Downloads folder.

#### 1a. Download wchisp

Click this link to download the tool:

- **[Download wchisp for Mac](https://github.com/ch32-rs/wchisp/releases/download/v0.3.0/wchisp-v0.3.0-macos-arm64.tar.gz)** *(`wchisp-v0.3.0-macos-arm64.tar.gz`)*

> Prefer to see the source? It's on the [wchisp releases page](https://github.com/ch32-rs/wchisp/releases) - choose the file ending in **`macos-arm64.tar.gz`**.

#### 1b. Unzip it

Go to your **Downloads** folder in Finder and **double-click** the file you just downloaded (`wchisp-v0.3.0-macos-arm64.tar.gz`). It will unzip into a single file simply called **`wchisp`**. Leave it in Downloads.

#### 1c. Unlock it so your Mac will run it

Because this tool is downloaded from the internet, macOS locks it by default. We unlock it with two quick commands. **Open Terminal** (see "Before you start" above), then paste these **one at a time**, pressing **Return** after each:

```bash
cd ~/Downloads
```

```bash
xattr -c wchisp && chmod +x wchisp
```

The first command moves Terminal into your Downloads folder (where the `wchisp` file is). The second one unlocks it. Neither prints anything if it works, that's fine.

> **Check it worked:** paste `./wchisp --version` and press Return. If you see a version number (like `wchisp 0.3.0`), you're all set.

> If macOS still pops up a warning that it "cannot verify the developer," click **Cancel**, then go to **System Settings → Privacy & Security**, scroll down, and click **Open Anyway** next to the wchisp message - then run `./wchisp --version` again.

---

### 2. Download the firmware

First work out which version of the knob you have by looking at its USB connector, then download the **matching** firmware and leave it in your **Downloads** folder.

> ⚠️ **Important:** the firmware must match your knob's version. Flashing **Direct** firmware onto an **Original** knob (or the other way round) will stop it working. When in doubt, check the connector before you download.

**Original version** - has a **USB Micro-B** or a **USB-C** socket (you plug a cable into it):

- **Volume knob:** [tiny_usb_knob_2.0.bin](tiny_usb_knob_2.0.bin)
- **MIDI knob:** [tiny_midi_knob_1.0.bin](tiny_midi_knob_1.0.bin)

**Direct version (V1 or V2)** - has a **USB Type-A plug** built in (it plugs straight into your USB port, no cable):

- **Volume knob:** [hid_knob_DIRECT.bin](hid_knob_DIRECT.bin)
- **MIDI knob:** *not available for Direct versions.*

> If your browser warns that the file "can't be downloaded safely," choose **Keep** - it's just a firmware file.

---

### 3. Put the device in Firmware Flashing Mode

1. Unplug the knob if it's plugged in.
2. **Press and hold the button down**, and - while still holding it - plug the knob into your Mac.
3. Keep holding for a moment, then let go.

If it worked, you'll see the **LED flicker for about 1 second** as you plug it in. That flicker means the knob is in Firmware Flashing Mode and ready.

> Didn't see the flicker? Unplug it and try again, making sure you're holding the button down **before** it touches the Mac.

---

### 4. Check that your Mac can see the knob

First, make sure Terminal is still in your Downloads folder (where the `wchisp` file lives). If you closed and reopened Terminal since Step 1, paste this and press **Return**:

```bash
cd ~/Downloads
```

Now paste this and press **Return**:

```bash
./wchisp info
```

- If it prints a few lines of chip details, great - your Mac sees the knob. Continue to Step 5.
- If it says something like **"device not found"**, the knob isn't in flashing mode. Repeat Step 3 and try `./wchisp info` again.

---

### 5. Flash the new firmware

This is the easy part. You're going to type the start of a command and then let the Mac fill in the file location for you:

1. Type this into Terminal, **including the space at the end** - but do **not** press Return yet:

   ```
   ./wchisp flash 
   ```

2. Open your **Downloads** folder in Finder, then **drag the firmware file you downloaded** (e.g. `tiny_usb_knob_2.0.bin`) **into the Terminal window** and let go. The full file location appears automatically after the command.

3. Now press **Return**.

wchisp will erase, write, and double-check the firmware, then restart the knob for you. Wait until it says it's finished and the blinking cursor returns. **Don't unplug the knob while it's flashing.**

---

### 6. Test the device

Once flashing finishes, the knob restarts on its own and works like a normal USB device again. To check it:

- Refresh the [Web Config UI](https://usbknob.com) page (or click **'Scan'**) and confirm the knob shows up and responds.

That's it.

---

### Troubleshooting

- **`./wchisp info` shows "device not found"** - the knob isn't in flashing mode. Redo Step 3 (look for the LED flicker), then try again.
- **`no such file or directory` when you run `./wchisp …`** — Terminal isn't in your Downloads folder. Paste `cd ~/Downloads` and press Return, then try again. (This also happens if you've moved the `wchisp` file out of Downloads.)
- **macOS says it "cannot verify the developer" / "wchisp can't be opened"** — go to **System Settings → Privacy & Security**, scroll down, and click **Open Anyway** next to the wchisp message, then run your command again. (Re-running `xattr -c wchisp` from Step 1c also fixes this.)
- **Anything else** — unplug the knob, close Terminal, reopen it, and start again from Step 4 (`cd ~/Downloads` first). A fresh start fixes most issues.

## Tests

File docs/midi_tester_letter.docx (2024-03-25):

Hi,

Thanks so much for helping me test the Tiny USB Midi Knob!

Instructions

1. Plug it in using a Micro-USB Type B cable.
2. Your computer should recognize it as a device called ‘Tiny Midi Knob’.
3. Twist or click the knob to send CC messages.
4. Configure the CC messages at https://midi.skilbeck.com

NOTE

Please read this: If your Tiny USB Midi Knob doesn’t work but flashes slowly after you’ve plugged it in, that means the USB connection failed. This is because your USB cable is a ‘Charger Only’ cable without data lines. Please use a data-enabled cable! If you suspect the cable, try another device with it to test it. If that also doesn’t work, it’s time to find another cable.

Please let me know how you get on?

You can email me: midi@charlie.skilbeck.com

Or message me on Reddit (u/cskilbeck)

Or Tweet me @cskilbeck

Thanks again for your help – looking forward to hearing from you.

Charlie.

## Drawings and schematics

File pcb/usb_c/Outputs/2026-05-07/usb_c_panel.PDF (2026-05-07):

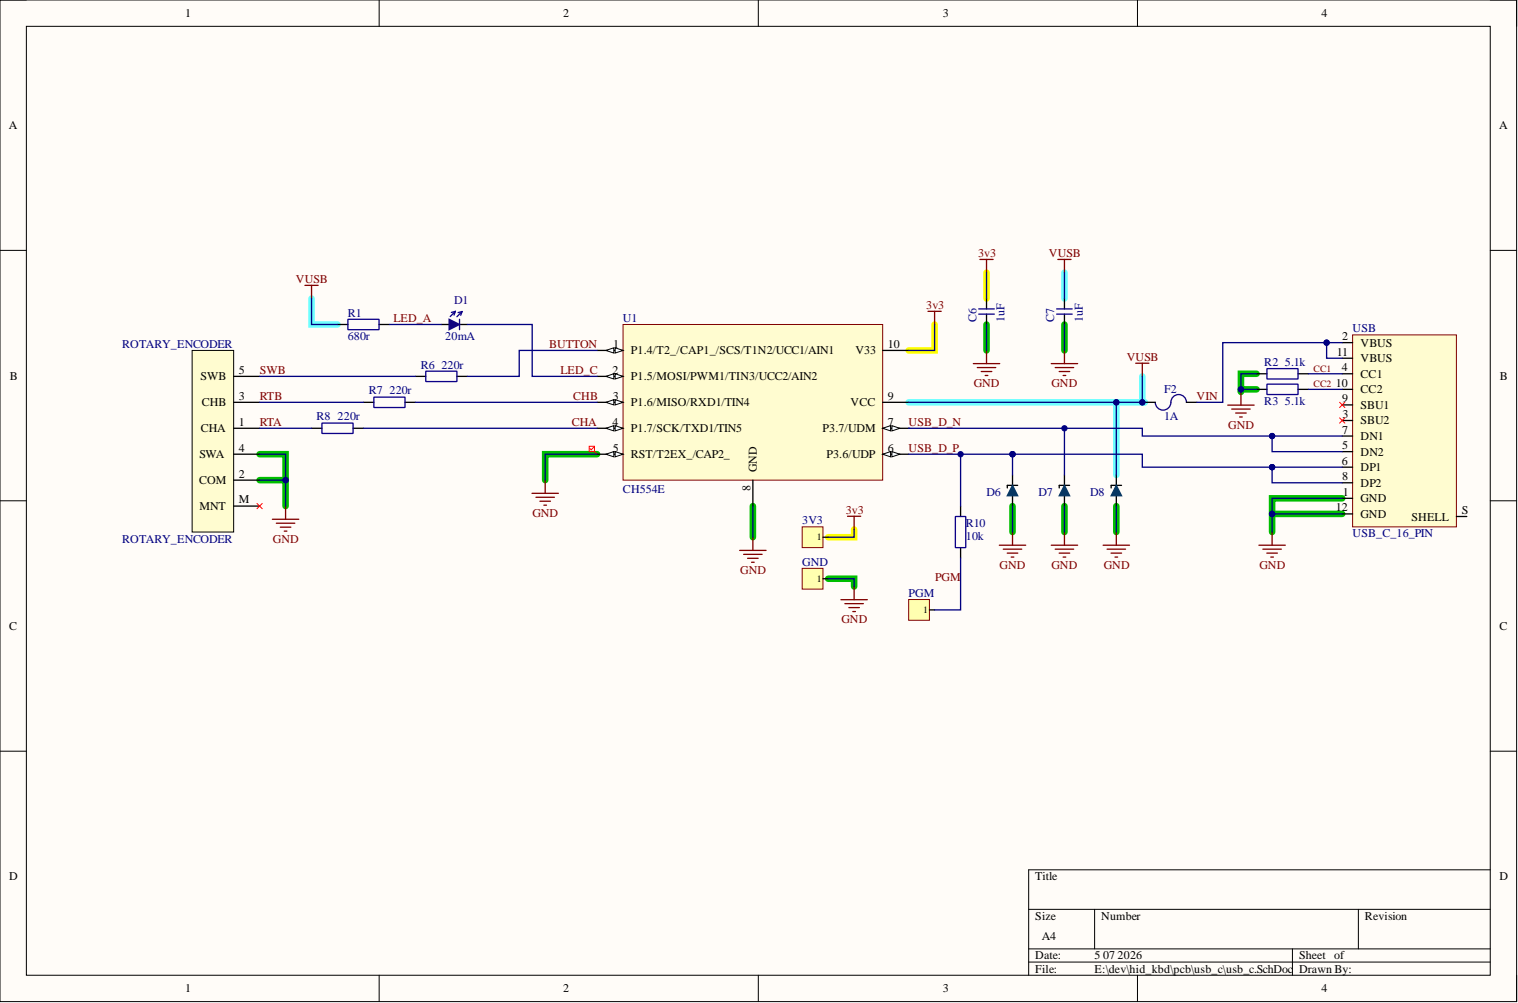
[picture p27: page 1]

6 USB_ D _P

Designator | Quantity | Comment | Description | Footprint | JLCPCBPart #
C6, C7 | 2 1uF | | MLCC | MLCC_0603 | C29936
D1 | 1 20mA | | LED | SMT_LED_0603 | C205445
D6, D7, D8 | 3 TVS_DIODE | | TVSDiode | TVS_DIODE | C151980
F2 | 1 1A | | Resettablefuse | FUSE0603_1608 0.5MM | C210357
R1 | 1 680r | | Resistor | SMT_RES_0603 | C23228
R2, R3 | 2 5.1k | | Resistor | SMT_RES_0603 | C25804
R6, R7, R8 | 3 220r | | Resistor | SMT_RES_0603 | C27592
R10 | 1 10k | | Resistor | SMT_RES_0603 | C25804
U1 | 1 CH554E | | CH554E | MSOP10 | C111293
USB | 1 USB_C_16_PIN | | USBReceptacleTYPE-C16PIN 2MD | USB_C_16PIN | C2765186

### Electrical Rules Check Report

Class | Document | Message Successful Compile for
Thursday 7 May 2026 10:07:49 PM | Page 1 of 1

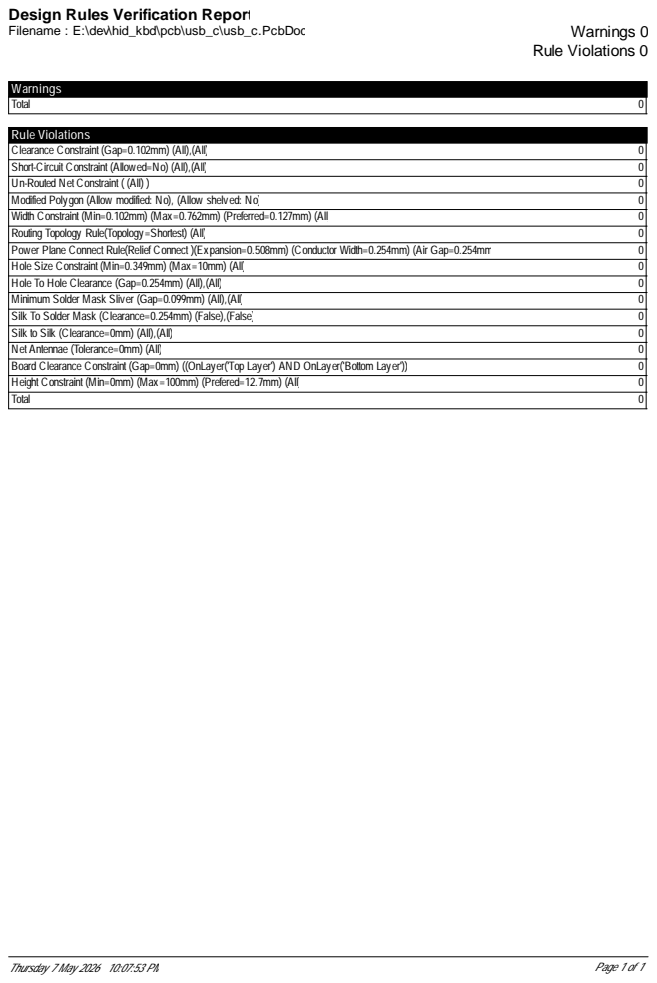
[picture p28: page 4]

Design Rules Verification Report

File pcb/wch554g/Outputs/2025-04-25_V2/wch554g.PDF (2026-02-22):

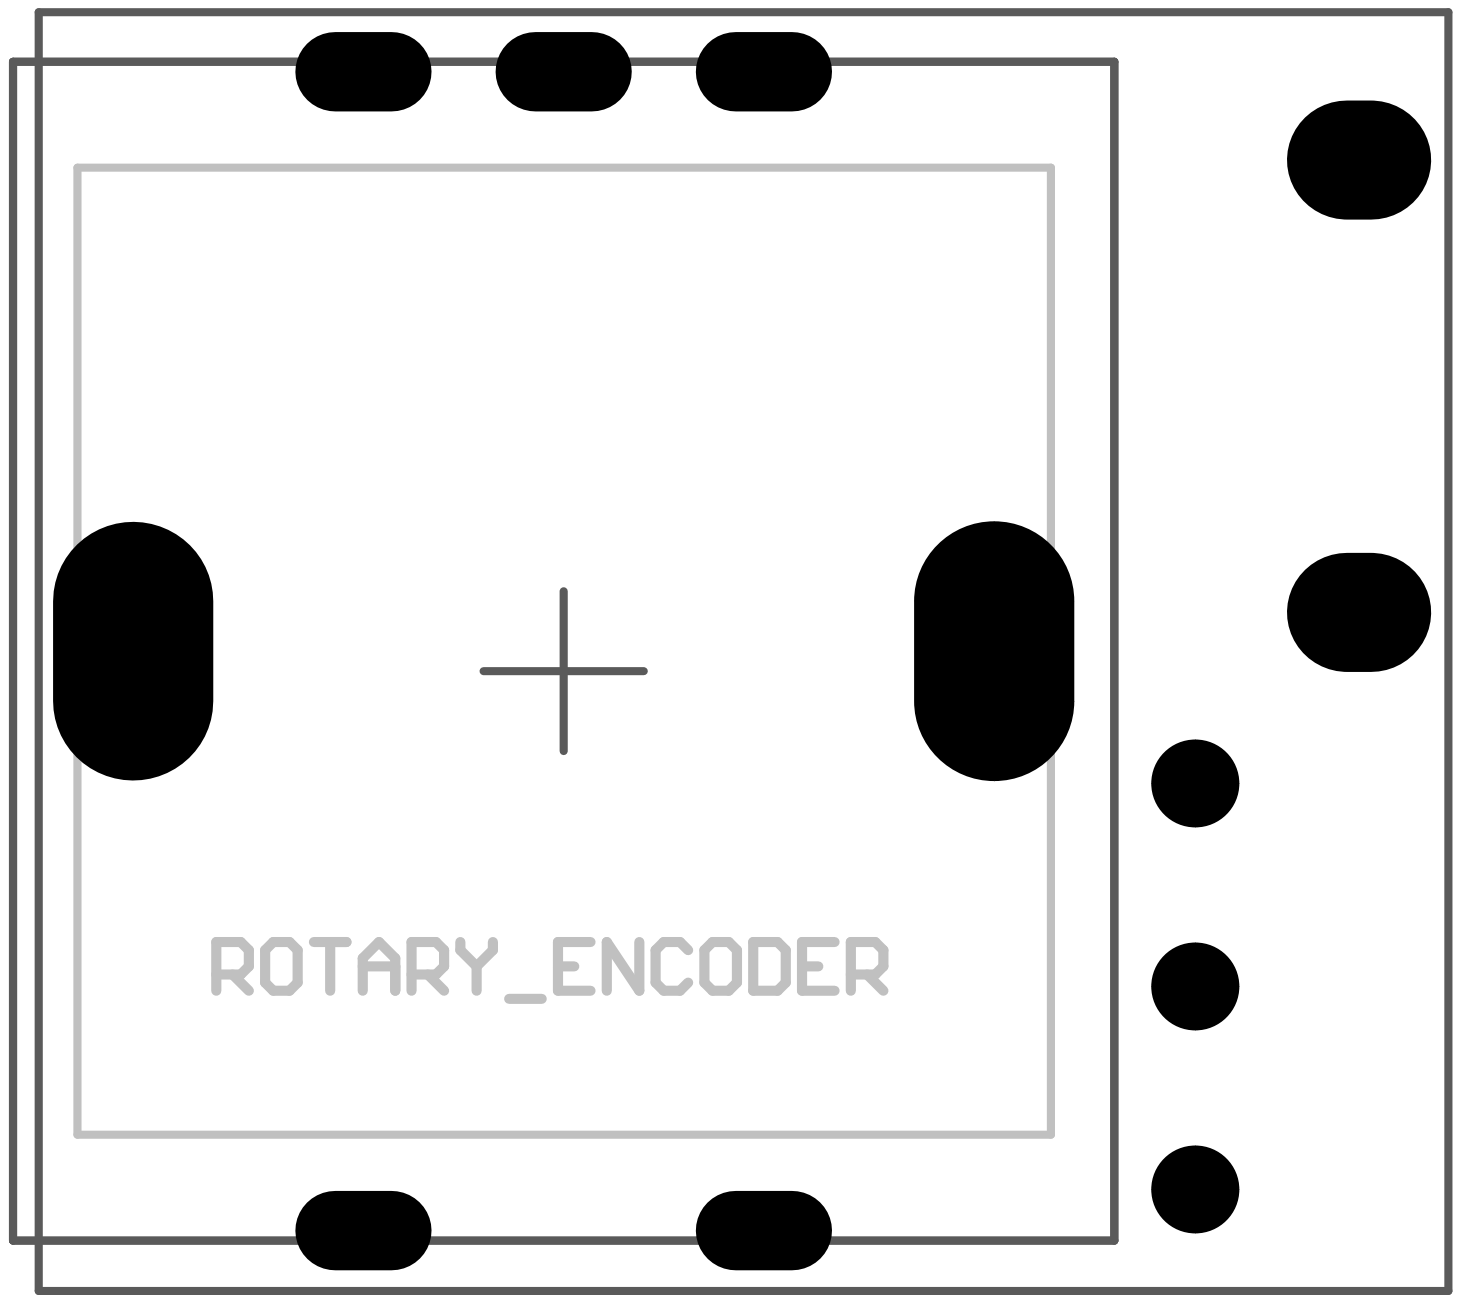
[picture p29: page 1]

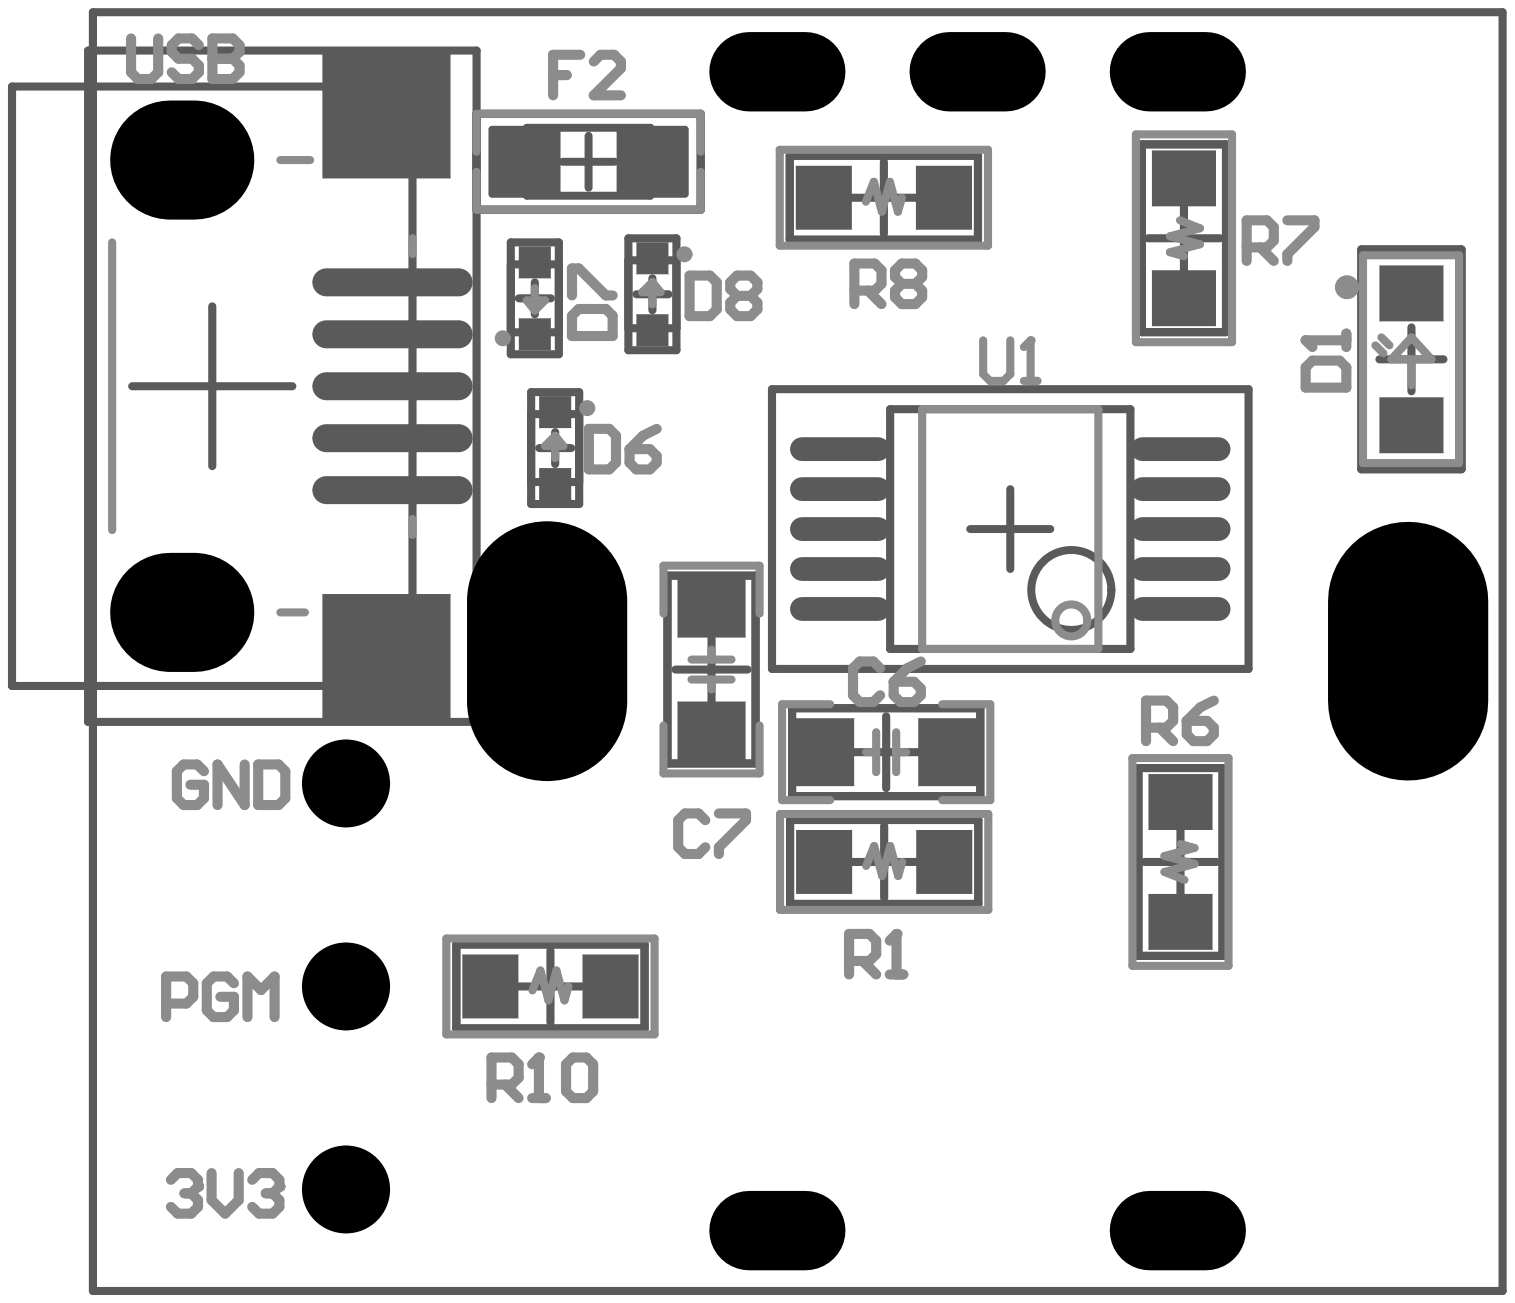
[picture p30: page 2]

Comment | Designator | Footprint | JLCPCBPart #
1uF | C6 | MLCC_0603 | C29936
1uF | C7 | MLCC_0603 | C29936
20mA | D1 | SMT_LED_0603 | C205445
TVS_DIODE | D6 | TVS_DIODE | C151980
TVS_DIODE | D7 | TVS_DIODE | C151980
TVS_DIODE | D8 | TVS_DIODE | C151980
1A | F2 | FUSE0603 | C210357
680r | R1 | SMT_RES_0603 | C23228
220r | R6 | SMT_RES_0603 | C27592
220r | R7 | SMT_RES_0603 | C27592
220r | R8 | SMT_RES_0603 | C27592
10k | R10 | SMT_RES_0603 | C25804
CH554E | U1 | MSOP10 | C111293
USBMicro | USB | USBMICROB | C397452

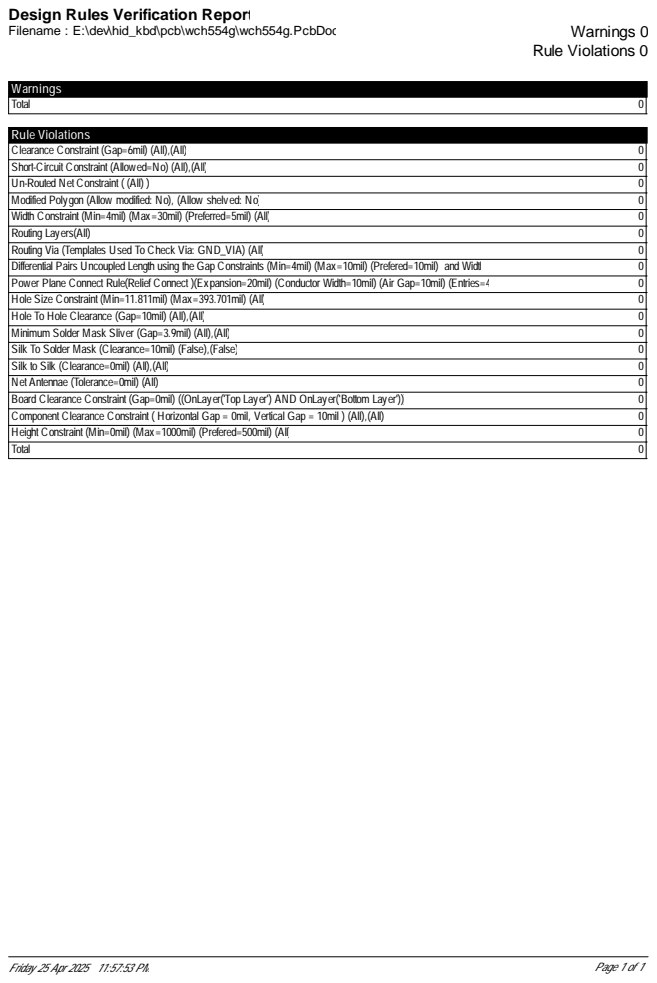
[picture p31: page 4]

Design Rules Verification Report

### Electrical Rules Check Report

Class | Document | Message Successful Compile for
Friday 25 Apr 2025 11:57:54 PM | Page 1 of 1

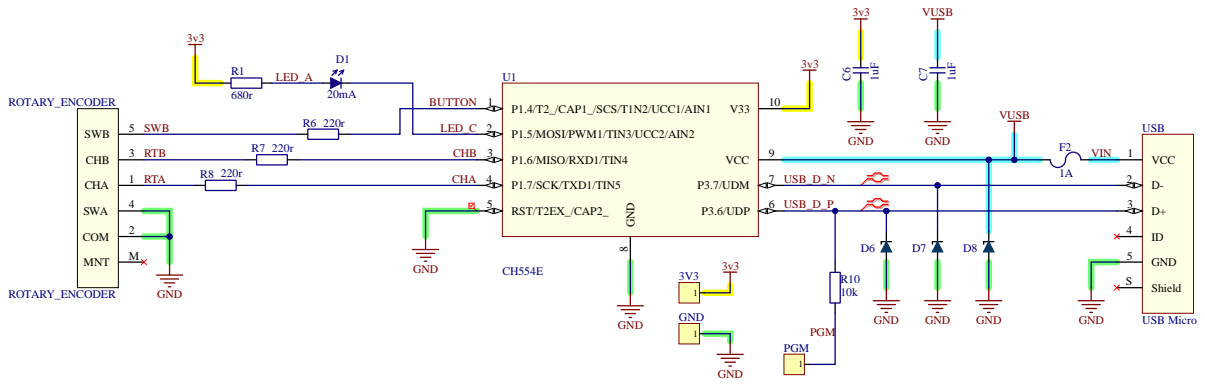
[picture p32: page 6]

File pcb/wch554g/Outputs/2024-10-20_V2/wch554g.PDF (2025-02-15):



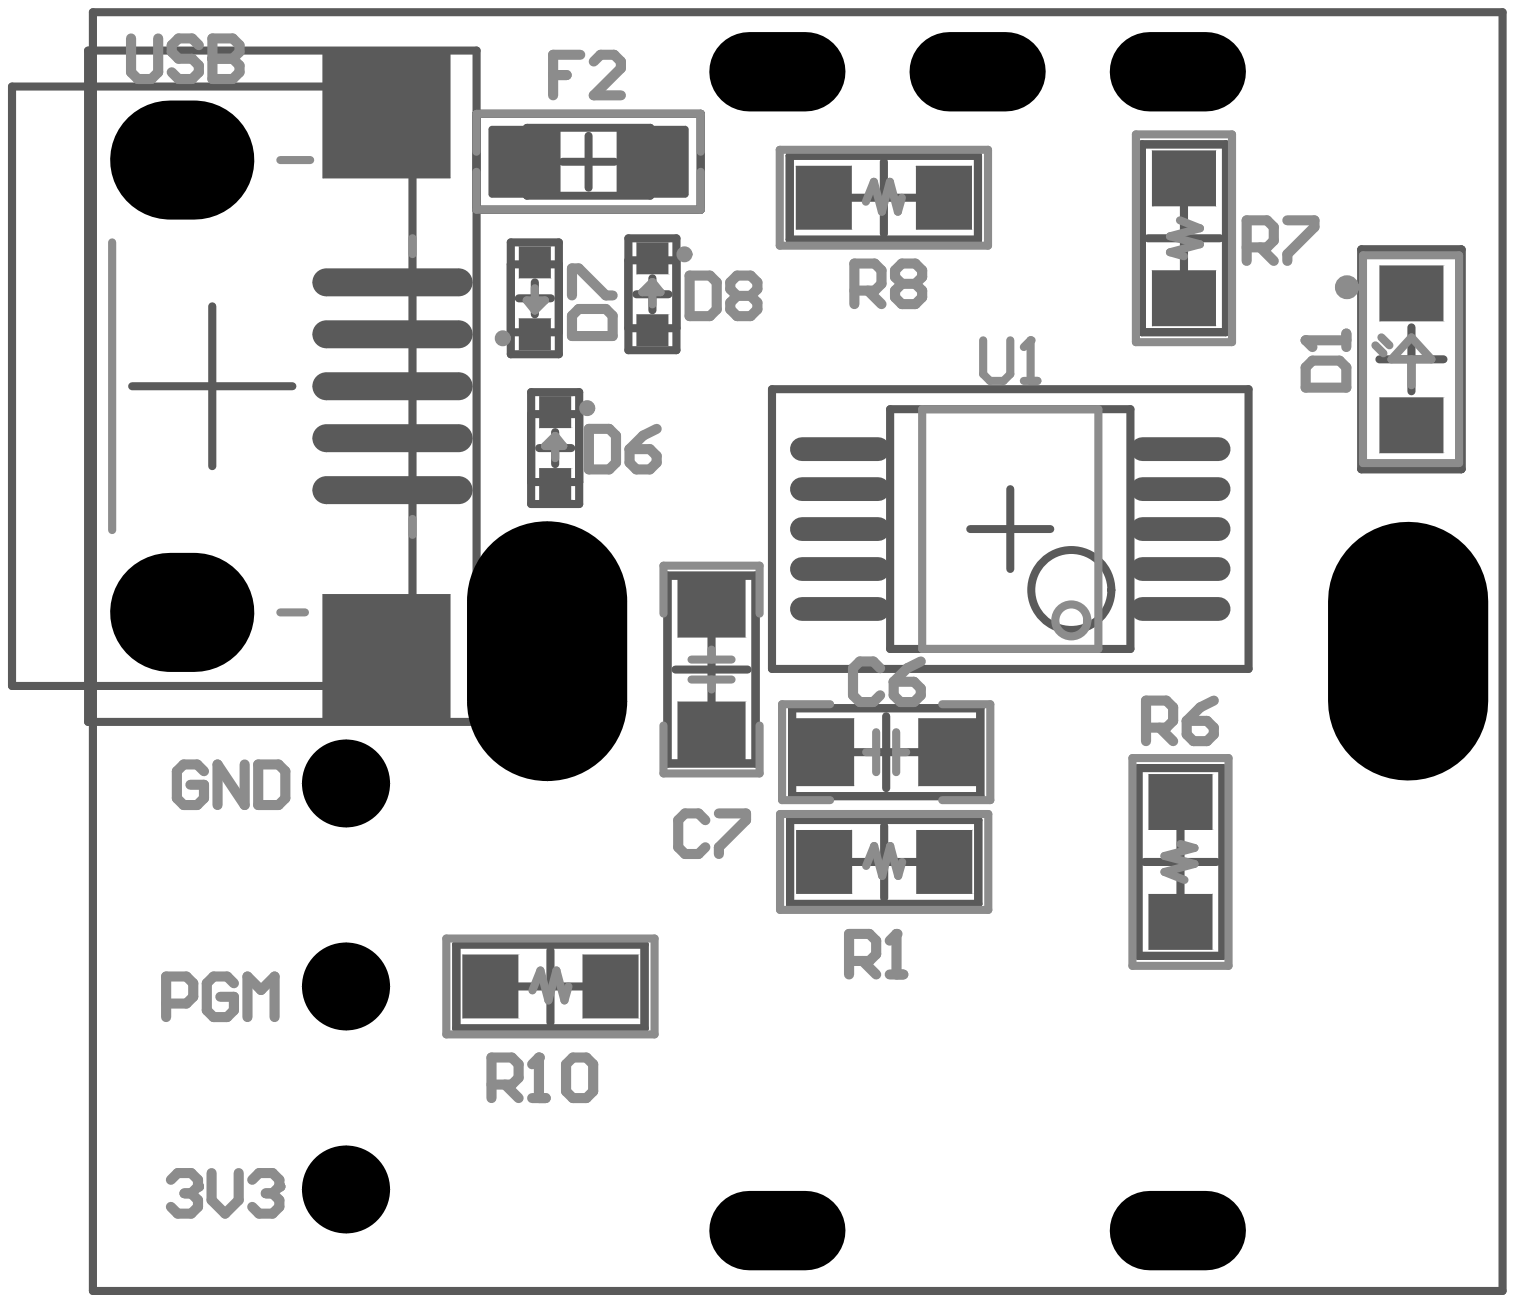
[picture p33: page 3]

Comment | Designator | Footprint | JLCPCBPart #
1uF | C6 | MLCC_0603 | C29936
1uF | C7 | MLCC_0603 | C29936
20mA | D1 | SMT_LED_0603 | C205445
TVS_DIODE | D6 | TVS_DIODE | C151980
TVS_DIODE | D7 | TVS_DIODE | C151980
TVS_DIODE | D8 | TVS_DIODE | C151980
1A | F2 | FUSE0603 | C210357
680r | R1 | SMT_RES_0603 | C23228
220r | R6 | SMT_RES_0603 | C27592
220r | R7 | SMT_RES_0603 | C27592
220r | R8 | SMT_RES_0603 | C27592
10k | R10 | SMT_RES_0603 | C25804
CH554E | U1 | MSOP10 | C111293
USBMicro | USB | USBMICROB | C397452

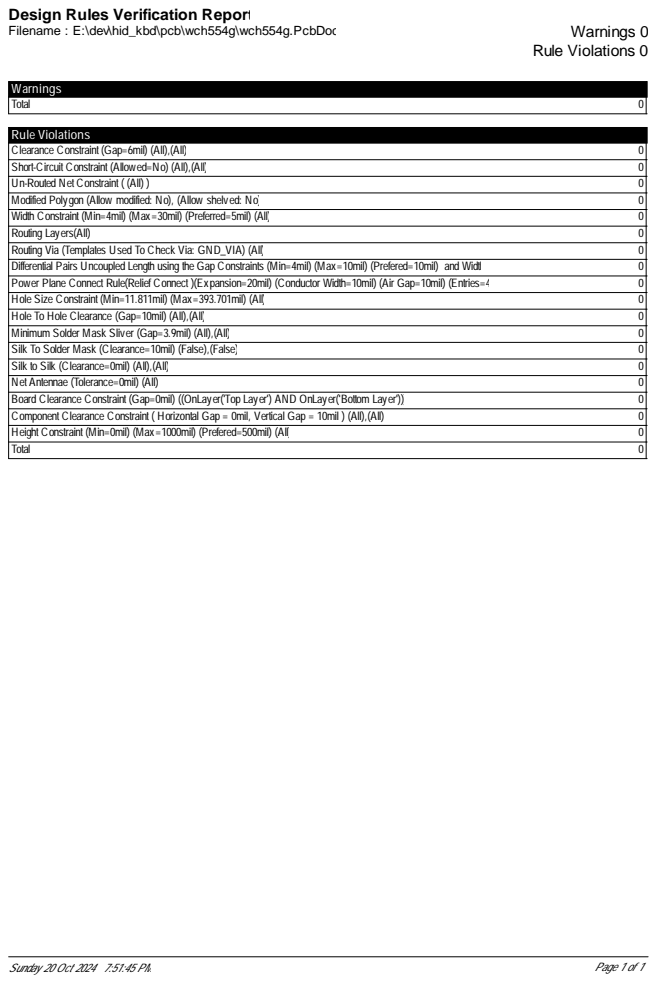
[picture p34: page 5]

Design Rules Verification Report

### Electrical Rules Check Report

Class | Document | Message Successful Compile for
Sunday 20 Oct 2024 7:51:45 PM | Page 1 of 1

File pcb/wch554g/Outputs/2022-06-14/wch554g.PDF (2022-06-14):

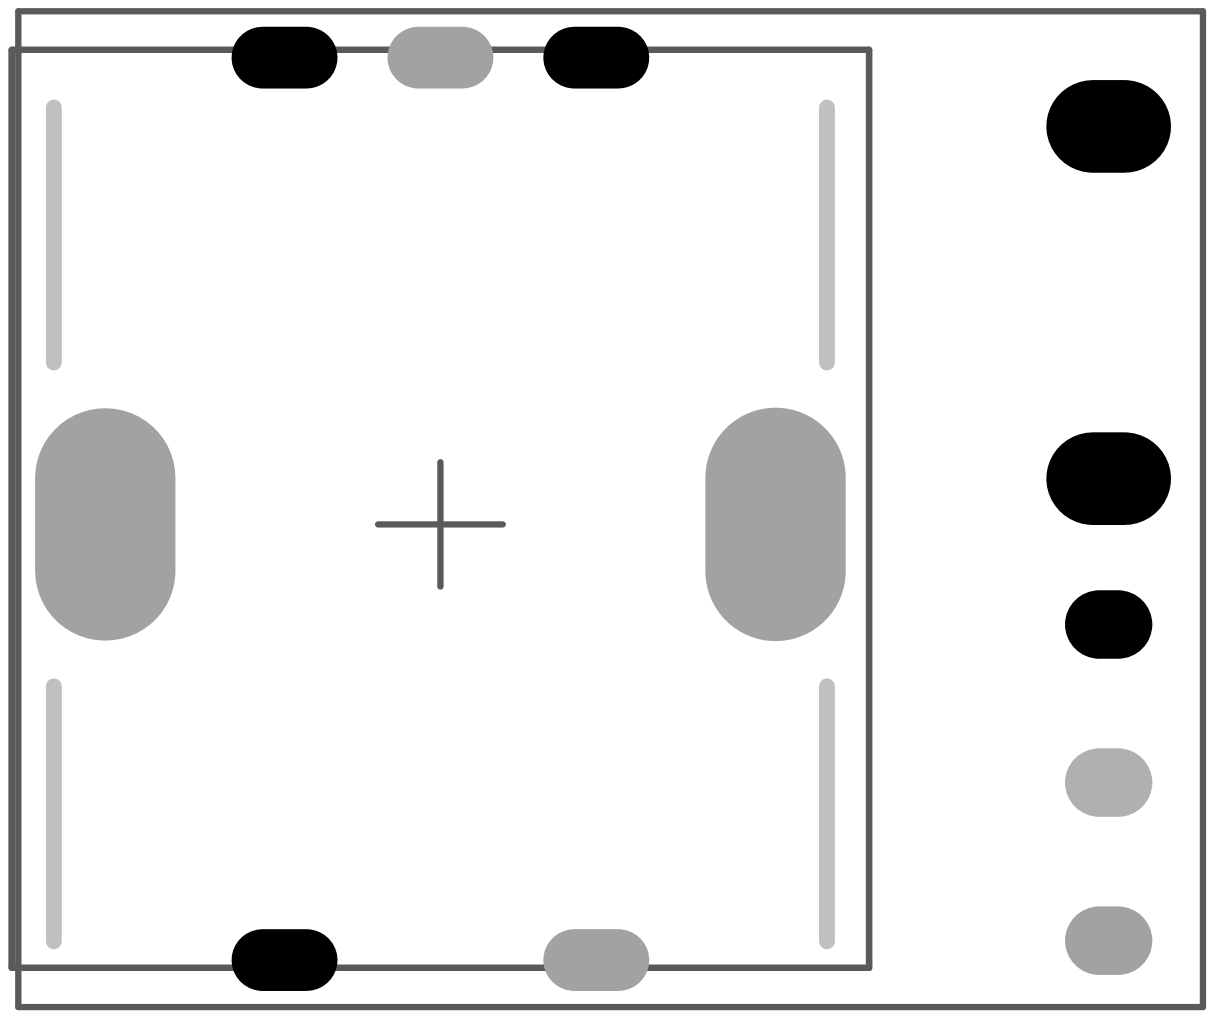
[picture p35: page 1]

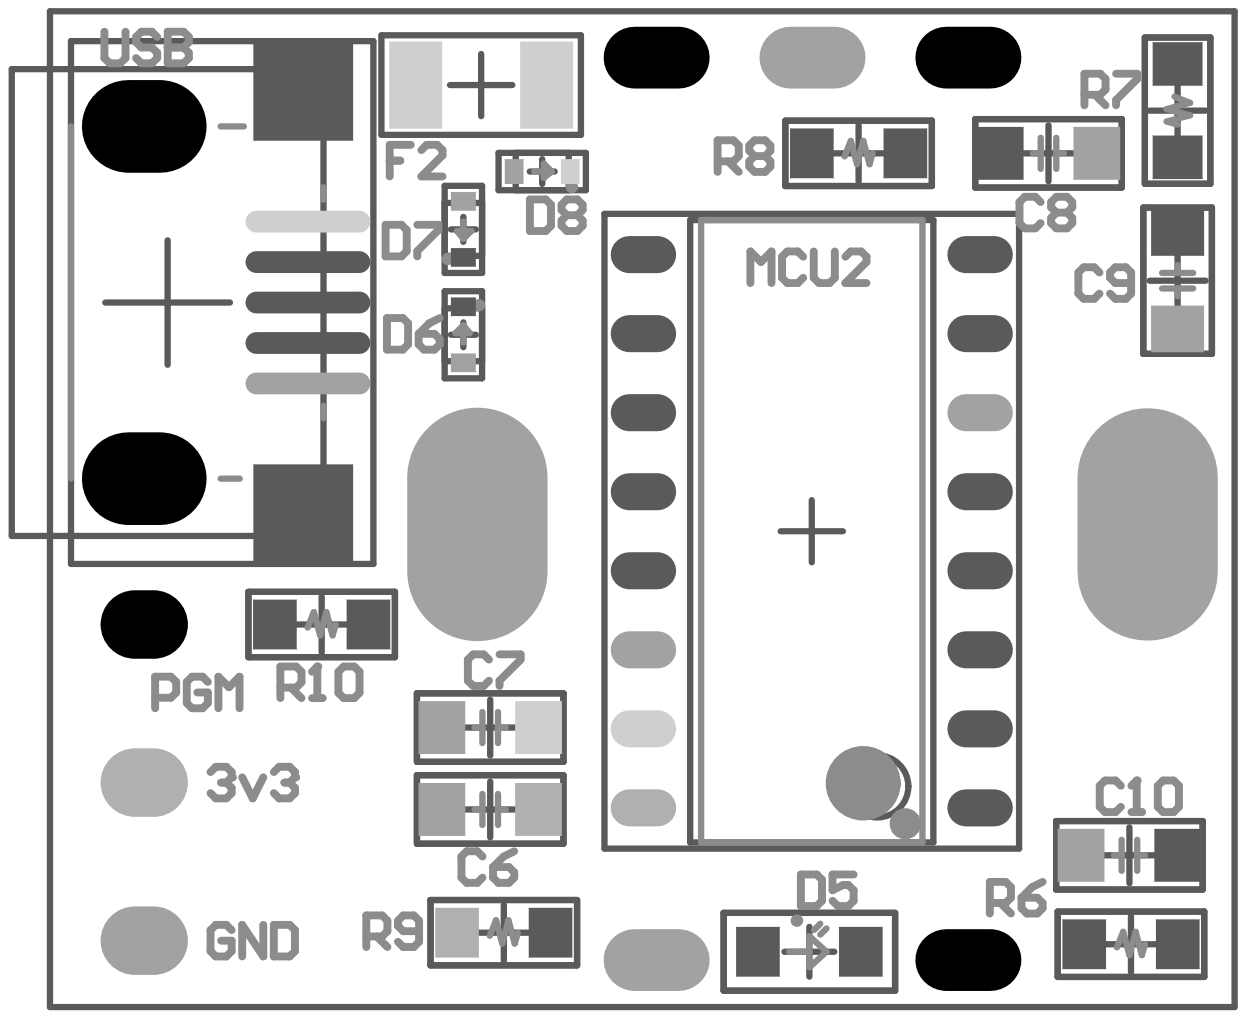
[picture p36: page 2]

Footprint | Quantity | Designator | Description | Value | JLCPCB Part #
MLCC 0603 | 2 C6, C7 | | MLCC | 1uF | C105524
MLCC 0603 | 3 C8, C9, C10 | | MLCC | 6.8nF | C1631
SMT LED 0603 | 1 D5 | | LED | 20mA | C138545
SODFL 98x40 2 pin | 3 D6, D7, D8 | | TVS Diode | TVS_DIODE | C384848
FUSE_0805 | 1 F2 | | FUSE | 1A | C70061
SOP16 x1.27 | 1 MCU2 | | CH554G SOP16 MCU | CH554G | C114295
0603 SMT Resistor | 3 R6, R7, R8 | | Resistor | 68r | C27592
0603 SMT Resistor | 1 R9 | | Resistor | 680r | C23228
0603 SMT Resistor | 1 R10 | | Resistor | 10k | C22765
USB Micro B Receptacle | 1 USB | | USB Receptacle | USB Micro | C397452

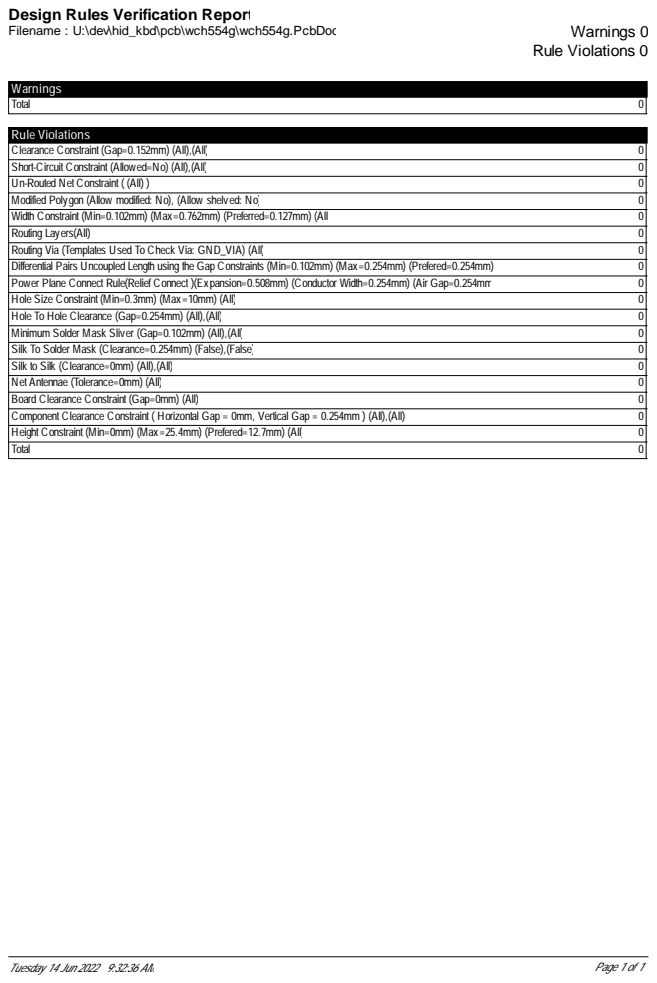
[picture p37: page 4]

Design Rules Verification Report

### Electrical Rules Check Report

Class | Document | Message Successful Compile for
Tuesday 14 Jun 2022 9:32:36 AM | Page 1 of 1

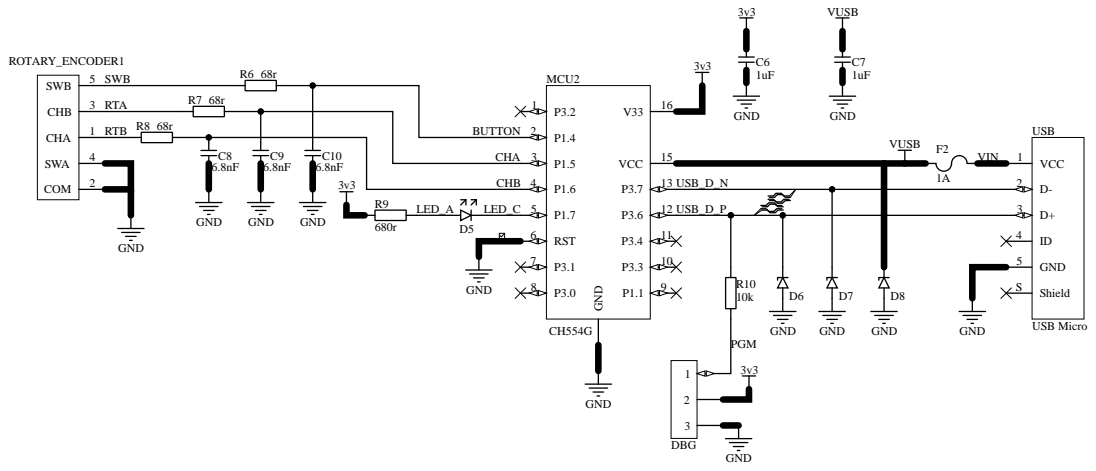
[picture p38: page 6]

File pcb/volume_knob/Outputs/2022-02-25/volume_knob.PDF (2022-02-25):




Push button rotary encoder

Designator | Quantity | Value | Footprint | Detail | Notes | Supplier Part Number 1
C1, C11 | 2 2.2uF | | CAPC1608X07L | MLCC 0603 | Any suitable
C3 | 1 1uF | | CAPC1608X07L | MLCC 0603 | Any suitable
C8, C10 | 2 3.3nF | | CAPC1608X07L | MLCC 0603 | Any suitable
C9 | 1 100nF | | CAPC1608X07L | MLCC 0603 | Any suitable
D1, D2, D3 | 3 | | SODFL98X40-2L | SODFL, 0.6x1.0mm | Any suitable USB TVS diodes | C312244
LDO | 1 3.3v / | 200mA | SOT95P237X110-3L | SOT23x3 2.90x2.37mm Pitch 0.95mm | Orsimilar | C479053
LED | 1 20mA | | SMT_LED_0603 | SMT LED 0603 | Any suitable
MCU | 1 | | TSOP65P630X120-20L | TSOPx20 6.45x4.35mm Pitch 0.65mm
R2 | 1 520r | | RESC1608X05L | 0603 SMT Resistor | Any suitable 1%
R5, R6 | 2 120 | | RESC1608X05L | 0603 SMT Resistor | Any suitable 1%
R7 | 1 2K | | RESC1608X05L | 0603 SMT Resistor | Any suitable 1%
ROTARY ENCODER | 1 | | PEC12R-4XXXF-SXXXX_1 | Rotary encoder | Any suitable
USB | 1 | | USB MICRO B JLCPCB | USB Micro B Receptacle | | C397452


Design Rules Verification Report

### Electrical Rules Check Report

Class | Document | Message Successful Compile for
Friday 25 Feb 2022 11:03:40 PM | Page 1 of 1

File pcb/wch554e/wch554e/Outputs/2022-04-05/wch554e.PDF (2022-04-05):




RST/T2EX_/CAP2_ 5 | USB_D_P | | D+ 3

Shield S

Designator | Quantity | Comment | Description | Footprint | JLCPCB Part #
U1 | 1 | | CH554E | MSOP10 3x3 x 0.5 | C111293
F1 | 1 1A | | FUSE | FUSE_0805 | C70061
D4 | 1 | | LED | SMT LED 0603 | C434424
C1, C2 | 2 1uF | | MLCC | MLCC 0603 | C105524
C3, C4, C5 | 3 10nF | | MLCC | MLCC 0603 | C519509
R1, R2, R3 | 3 120r | | Resistor | 0603 SMT Resistor | C22787
R4 | 1 10k | | Resistor | 0603 SMT Resistor | C25804
R5 | 1 680r | | Resistor | 0603 SMT Resistor | C23228
D1, D2, D3 | 3 | | TVS Diode | SODFL 98x40 2 pin | C384848
J1 | 1 | | USB Receptacle | USB Micro B Receptacle | C397452


Design Rules Verification Report

### Electrical Rules Check Report

Class | Document | Message
Warning | wch554e.SchDoc | GND contains IO Pin and Power Pin objects (Pin U1-5, Pin DBG-3, Pin U1-8)
Tuesday 5 Apr 2022 6:56:45 PM | Page 1 of 1

Layer | Board Layer Stack | Name | Material | Thickness | Constant
1 | | Top Paste
2 | | Top Overlay
3 | | Top Solder | SM-001 | 0.025mm | 4
4 | | Top Layer | Copper | 0.035mm
5 | | Dielectric 1 | Core-043 | 0.680mm | 4.3
6 | | Bottom Layer | Copper | 0.035mm
7 | | Bottom Solder | SM-001 | 0.025mm | 4
8 | | Bottom Overlay
9 | | Bottom Paste
| Height : 0.801mm

# Board Stack Report

Stack Up | Layer Stack

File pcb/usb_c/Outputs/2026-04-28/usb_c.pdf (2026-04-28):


6 USB_ D _P


Design Rules Verification Report

### Electrical Rules Check Report

Class | Document | Message Successful Compile for
Tuesday 28 Apr 2026 5:41:10 PM | Page 1 of 1


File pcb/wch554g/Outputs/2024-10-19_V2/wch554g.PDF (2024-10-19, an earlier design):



Comment | Designator | Footprint | JLCPCBPart #
1uF | C6 | MLCC_0603 | C29936
1uF | C7 | MLCC_0603 | C29936
20mA | D1 | SMT_LED_0603 | C205445
TVS_DIODE | D6 | TVS_DIODE | C151980
TVS_DIODE | D7 | TVS_DIODE | C151980
TVS_DIODE | D8 | TVS_DIODE | C151980
1A | F2 | FUSE0603 | C210357
680r | R1 | SMT_RES_0603 | C23228
220r | R6 | SMT_RES_0603 | C27592
220r | R7 | SMT_RES_0603 | C27592
220r | R8 | SMT_RES_0603 | C27592
10k | R10 | SMT_RES_0603 | C25804
CH554E | U1 | MSOP10 | C111293
USBMicro | USB | USBMICROB | C397452


Design Rules Verification Report

### Electrical Rules Check Report

Class | Document | Message Successful Compile for
Saturday 19 Oct 2024 11:49:36 AM | Page 1 of 1


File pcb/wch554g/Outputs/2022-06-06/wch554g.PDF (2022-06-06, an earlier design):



Footprint | Quantity | Designator | Description | Value | JLCPCB Part #
MLCC 0603 | 2 C6, C7 | | MLCC | 1uF | C105524
MLCC 0603 | 3 C8, C9, C10 | | MLCC | 10nF | C519509
SMT LED 0603 | 1 D5 | | LED | 20mA | C434424
SODFL 98x40 2 pin | 3 D6, D7, D8 | | TVS Diode | TVS_DIODE | C384848
FUSE_0805 | 1 F2 | | FUSE | 1A | C70061
SOP16 x1.27 | 1 MCU2 | | CH554G SOP16 MCU | CH554G | C114295
0603 SMT Resistor | 3 R6, R7, R8 | | Resistor | 120r | C22787
0603 SMT Resistor | 1 R9 | | Resistor | 680r | C23228
0603 SMT Resistor | 1 R10 | | Resistor | 10k | C25804
USB Micro B Receptacle | 1 USB | | USB Receptacle | USB Micro | C397452


Design Rules Verification Report

### Electrical Rules Check Report

Class | Document | Message Successful Compile for
Monday 6 Jun 2022 2:24:45 PM | Page 1 of 1


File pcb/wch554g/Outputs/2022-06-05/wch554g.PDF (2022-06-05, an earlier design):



Footprint | Quantity | Designator | Description | Value | JLCPCB Part #
MLCC 0603 | 2 C6, C7 | | MLCC | 1uF | C105524
MLCC 0603 | 3 C8, C9, C10 | | MLCC | 10nF | C519509
SMT LED 0603 | 1 D5 | | LED | 20mA | C434424
SODFL 98x40 2 pin | 3 D6, D7, D8 | | TVS Diode | TVS_DIODE | C384848
FUSE_0805 | 1 F2 | | FUSE | 1A | C70061
USB Micro B Receptacle | 1 J2 | | USB Micro B Receptacle | USB | C397452
SOP16 x1.27 | 1 MCU2 | | CH554G SOP16 MCU | CH554G | C114295
0603 SMT Resistor | 3 R6, R7, R8 | | Resistor | 120r | C22787
0603 SMT Resistor | 1 R9 | | Resistor | 680r | C23228
0603 SMT Resistor | 1 R10 | | Resistor | 10k | C25804


Design Rules Verification Report

### Electrical Rules Check Report

Class | Document | Message Successful Compile for
Sunday 5 Jun 2022 7:55:02 PM | Page 1 of 1


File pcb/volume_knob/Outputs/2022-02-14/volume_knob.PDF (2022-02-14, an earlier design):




Push button rotary Encoder

SWCLK 5

Designator | Quantity | Value | Footprint | Detail | Notes | Supplier Part Number 1
C1, C11 | 2 2.2uF | | MLCC_0805 | MLCC 0805 | Any suitable
C3 | 1 1uF | | CAPC1608X07L | MLCC 0603 | Any suitable
C8, C10 | 2 3.3nF | | CAPC1608X07L | MLCC 0603 | Any suitable
C9 | 1 100nF | | CAPC1608X07L | MLCC 0603 | Any suitable
D1, D2, D3 | 3 | | SODFL98X40-2L | SODFL, 0.6x1.0mm | Any suitable USB TVS diodes | C312244
LDO | 1 200mA | | SOT95P237X110-3L | SOT23x3 2.90x2.37mm Pitch 0.95mm | Orsimilar | C479053
LED | 1 20mA | | SMT_LED_0603 | SMT LED 0603 | Any suitable
MCU | 1 | | TSOP65P630X120-20L | TSOPx20 6.45x4.35mm Pitch 0.65mm
R1 | 1 10k | | RESC1608X05L | 0603 SMT Resistor | Any suitable 1%
R2 | 1 520r | | RESC1608X05L | 0603 SMT Resistor | Any suitable 1%
R3 | 1 1.5k | | RESC1608X05L | 0603 SMT Resistor | Any suitable 1%
R5, R6 | 2 120 | | RESC1608X05L | 0603 SMT Resistor | Any suitable 1%
R7 | 1 2K | | RESC1608X05L | 0603 SMT Resistor | Any suitable 1%
ROTARY ENCODER | 1 | | PEC12R-4XXXF-SXXXX_1 | Rotary encoder | Any suitable
USB | 1 | | USB MICRO B JLCPCB | USB Micro B Receptacle | | C397452


Design Rules Verification Report

### Electrical Rules Check Report

Class | Document | Message Successful Compile for
Monday 14 Feb 2022 11:01:11 PM | Page 1 of 1

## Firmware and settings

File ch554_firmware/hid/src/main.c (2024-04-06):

#include "main.h"

#define BOOT_FLASH_LED_COUNT 10
#define BOOT_FLASH_LED_SPEED 20

void main()
{
    clk_init();
    tick_init();
    uart0_init();
    led_init();
    encoder_init();

    if(BTN_BIT == 0) {    // if button held down when the device is plugged in, go to bootloader
        goto_bootloader();
    }

    EA = 1;    // global irq enable

    printf(CLEAR_CONSOLE "---------- %s ----------\nCHIP ID: %08lX\n", current_process->process_name, chip_id);

    load_config();
    usb_init();
    led_flash_n_times(BOOT_FLASH_LED_COUNT, BOOT_FLASH_LED_SPEED);
    usb_wait_for_connection();

    tick_wait(250);

    led_flash();

    current_process->on_init();

    bool button_state = false;
    uint8 button_debounce_ticks = 0;

    while(1) {

        bool pressed = false;
        bool released = false;
        bool new_state = !BTN_BIT;

        if(new_state != button_state && button_debounce_ticks > 1) {
            button_debounce_ticks = 0;
            pressed = new_state;
            released = !new_state;
            button_state = new_state;
        }

        if(TF2) {    // tick
            TF2 = 0;
            if(button_debounce_ticks <= 2) {
                button_debounce_ticks += 1;
            }
            current_process->on_tick();
            led_on_tick();
        }

        if(pressed) {
            current_process->on_press();
        }

        if(released) {
            current_process->on_release();
        }

        int8 direction = encoder_read();
        if(direction != 0) {
            current_process->on_rotate(direction);
        }

        for(uint8 i = 0; i < num_endpoints; ++i) {    // process or discard any incoming USB data
            uint8 got = usb.recv_len[i];
            if(got != 0 && current_process->on_usb_receive[i] != NULL) {
                current_process->on_usb_receive[i](got);
            }
            usb.recv_len[i] = 0;
        }

        current_process->on_update();

        led_update();
    }
}

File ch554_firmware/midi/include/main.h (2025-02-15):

//////////////////////////////////////////////////////////////////////

#pragma once

#pragma disable_warning 110
#pragma disable_warning 154

#include "vs_lint.h"

//////////////////////////////////////////////////////////////////////

#if !defined(DEVICE)
#error Please define DEVICE

// uncomment one of these for VSCode section dimming thing
#define DEVICE DEVICE_DEVKIT
// #define DEVICE DEVICE_DIRECT
// #define DEVICE DEVICE_ORIGINAL
#endif

//////////////////////////////////////////////////////////////////////

#define TICK_FREQ 1000

#define UART0_BAUD 115200

#define BOOTLOADER_FLASH_LED_COUNT 30
#define BOOTLOADER_FLASH_LED_SPEED 40

#define BOOT_FLASH_LED_COUNT 10
#define BOOT_FLASH_LED_SPEED 20

//////////////////////////////////////////////////////////////////////

// uncomment this line for full speed (12Mb), comment it out for low speed (1.5Mb)
#define USB_FULL_SPEED 1

#if defined(USB_FULL_SPEED)
#define USB_PACKET_SIZE 64
#else
#define USB_PACKET_SIZE 8
#endif

//////////////////////////////////////////////////////////////////////

#define FIRMWARE_CURRENT_VERSION 0x010000

#define FIRMWARE_VERSION ((FIRMWARE_CURRENT_VERSION << 8) | DEVICE)

//////////////////////////////////////////////////////////////////////
// MIDI_QUEUE_LEN must be a power of 2 and
// MIDI_QUEUE_LEN * sizeof(uint32) must be < USB_PACKET_SIZE (64) so
// effectively the max length is 16

#include "common.h"
#include "midi.h"
#include "xdata_extra.h"
#include "midi_config.h"

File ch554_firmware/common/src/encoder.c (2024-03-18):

#include "main.h"

//////////////////////////////////////////////////////////////////////

static __code uint8 const encoder_valid_bits[16] = { 0, 1, 1, 0, 1, 0, 0, 1, 1, 0, 0, 1, 0, 1, 1, 0 };

static uint8 encoder_state = 0;
static uint8 encoder_store = 0;

//////////////////////////////////////////////////////////////////////

void encoder_init()
{
    gpio_init(ROTA_PORT, ROTA_PIN, gpio_input_pullup);
    gpio_init(ROTB_PORT, ROTB_PIN, gpio_input_pullup);
    gpio_init(BTN_PORT, BTN_PIN, gpio_input_pullup);
}

//////////////////////////////////////////////////////////////////////

int8 encoder_read()
{
    uint8 a = 0;
    if(!ROTA_BIT) {
        a |= 1;
    }
    if(!ROTB_BIT) {
        a |= 2;
    }

    encoder_state <<= 2;
    encoder_state |= a;
    encoder_state &= 0xf;

    if(encoder_valid_bits[encoder_state] != 0) {
        encoder_store = (encoder_store << 4) | encoder_state;
        switch(encoder_store) {
        case 0xe8:
            return 1;
        case 0x2b:
            return -1;
        }
    }
    return 0;
}

// odd # of bits set (1 or 3) means it's valid

// 0  00 00 0
// 1  00 01 1
// 2  00 10 1
// 3  00 11 0
// 4  01 00 1
// 5  01 01 0
// 6  01 10 0
// 7  01 11 1
// 8  10 00 1
// 9  10 01 0
// A  10 10 0
// B  10 11 1
// C  11 00 0
// D  11 01 1
// E  11 10 1
// F  11 11 0

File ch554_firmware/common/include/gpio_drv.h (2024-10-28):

#pragma once

//////////////////////////////////////////////////////////////////////

#define PORT1 0x90
#define PORT3 0xB0

#if DEVICE == DEVICE_ORIGINAL

// USB Micro B version

#define ROTA_PORT PORT3
#define ROTB_PORT PORT3
#define BTN_PORT PORT3
#define LED_PORT PORT1

#define ROTA_PIN 1
#define ROTB_PIN 0
#define BTN_PIN 2
#define LED_PIN 4

#define LED_ON 0
#define LED_OFF 1

#elif DEVICE == DEVICE_DIRECT

// USB A version

#define ROTA_PORT PORT1
#define ROTB_PORT PORT1
#define BTN_PORT PORT1
#define LED_PORT PORT1

#define ROTA_PIN 6
#define ROTB_PIN 4
#define BTN_PIN 7
#define LED_PIN 5

#define LED_ON 0
#define LED_OFF 1

#elif DEVICE == DEVICE_DEVKIT

// CH554G Devkit version

#define UART_TX_PORT PORT3
#define UART_RX_PORT PORT3
#define ROTA_PORT PORT3
#define ROTB_PORT PORT3
#define BTN_PORT PORT3
#define LED_PORT PORT1

#define UART_TX_PIN 0
#define UART_RX_PIN 1
#define ROTA_PIN 3
#define ROTB_PIN 4
#define BTN_PIN 2
#define LED_PIN 6

#define LED_ON 1
#define LED_OFF 0

#elif DEVICE == DEVICE_ORIGINAL_V2

#define ROTA_PORT PORT1
#define ROTB_PORT PORT1
#define BTN_PORT PORT1
#define LED_PORT PORT1

#define BTN_PIN 4
#define LED_PIN 5
#define ROTA_PIN 6
#define ROTB_PIN 7

#define LED_ON 0
#define LED_OFF 1

#else

#error DEVICE NOT DEFINED!?

#endif

SBIT(ROTA_BIT, ROTA_PORT, ROTA_PIN);
SBIT(ROTB_BIT, ROTB_PORT, ROTB_PIN);
SBIT(BTN_BIT, BTN_PORT, BTN_PIN);
SBIT(LED_BIT, LED_PORT, LED_PIN);

//////////////////////////////////////////////////////////////////////

typedef enum gpio_state
{
    gpio_input_no_pullup = 0,
    gpio_output_push_pull = 1,
    gpio_output_open_drain = 2,
    gpio_input_pullup = 3
} gpio_state_t;

void gpio_init(uint8 port, uint8 bitpos, gpio_state_t state);

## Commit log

2022-02-05 flash debug led when knob activity
2022-02-05 idle between interrupts
2022-02-07 pcb begin
    [volume_knob.PcbDoc, volume_knob.PcbLib, volume_knob.PrjPcb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]
2022-02-09 0.6mm pcb thickness, move swd connector
    [volume_knob.PcbDoc, volume_knob.PcbLib, volume_knob.PrjPcb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]
2022-02-09 remove redundant termination resistors from usb
    [volume_knob.PcbDoc, volume_knob.SchDoc]
2022-02-10 add usb tvs diode array
    [volume_knob.PcbDoc, volume_knob.PcbLib, volume_knob.SchDoc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]
2022-02-10 halfway between shrink
    [volume_knob.PcbDoc, volume_knob.PcbLib, volume_knob.PrjPcb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]
2022-02-14 20x17 other usb
    [volume_knob.PcbDoc, volume_knob.PcbLib, volume_knob.SchDoc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]
2022-02-15 fix step output
    [volume_knob.PrjPcb, volume_knob.step]
2022-02-16 enclosure begin
    [473461001.sldprt]
2022-02-17 enclosure 0.1
2022-02-22 enclosure 1
    [bottom.SLDPRT, knob.SLDPRT, knob.STEP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]
2022-02-23 shrink 16x19
    [volume_knob.PcbDoc, volume_knob.PcbLib, volume_knob.PrjPcb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]
2022-02-24 firmware for stm32f042f4p6
2022-02-24 remove reset series resistor, replace hole with notch
    [volume_knob.PcbDoc, volume_knob.PcbLib, volume_knob.SchDoc]
2022-02-26 pcb production files
2022-02-27 enclosure for new pcb
    [enclosure2.SLDASM, knob.SLDPRT, lower.SLDPRT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]
2022-03-03 pcb noodle rounded corners
    [volume_knob.PcbDoc, volume_knob.PcbLib, volume_knob.SchDoc]
2022-03-15 stm32 board noodle
    [encoder.step, volume_knob.PcbDoc, volume_knob.PcbLib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]
2022-03-15 ch554e noodle
    [rotary_encoder.SLDPRT, rotary_encoder.STEP, wch554e.PcbDoc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]
2022-03-15 enclosure noodle
    [enclosure2.SLDASM, encoder.SLDPRT, encoder2.SLDPRT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]
2022-03-25 footprint! pinout!
    [wch554e.PcbDoc, wch554e.PcbLib, wch554e.SchDoc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]
2022-03-27 add bom, output
    [wch554e.PcbDoc, wch554e.PcbLib, wch554e.PrjPcb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]
2022-03-30 pulsing activity led
2022-04-07 enclosure for 0.8mm pcb
    [enclosure.SLDASM, lower.SLDPRT, pcb.SLDPRT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]
2022-04-18 usb A
    [CUI_DEVICES_UP2-AH-1-TH.step, wch554e.PcbDoc, wch554e.PcbLib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]
2022-05-28 hold button to jump to bootloader
2022-05-28 some pcb noodle
    [wch554e.PcbLib, wch554e.PrjPcb, wch554e.SchLib]
2022-06-05 fallout from ch554g
    [wch554e.PcbDoc, wch554e.PcbLib, wch554e.PrjPcb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]
2022-06-16 add dfm, p_l
    [p_l_100.xlsx]
2022-06-30 triple click to change encoder direction
2022-07-01 fix enclosure after losing changes
    [enclosure.SLDASM, lower.SLDPRT, upper.SLDPRT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]
2022-10-23 update enclosure
    [enclosure.SLDASM, knob.SLDPRT, lower.SLDPRT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]
2022-10-25 firmware composite usb device
2023-05-26 pcblib tweaks
    [wch554g.PcbDoc, wch554g.SchDoc]
2024-02-19 rotary encoder wip
2024-02-20 queue usb messages to avoid congestion
    [main.c]
2024-02-21 web page device scanning
2024-02-25 toggle load_save slot correctly
2024-02-26 splitting some things out of main
    [orders.xlsx]
2024-02-26 tidy up
    [cc_list.xlsx]
2024-03-02 update firmware mode button
2024-03-02 fw flash mode button
    fix checkbox label ids
    [main.c]
2024-03-02 rejig flash slot save thing
2024-03-02 LED ui v0.1
2024-03-02 fix CCDropDown button text color
2024-03-02 led flashing based on config
2024-03-02 flash rather than toggle led
2024-03-02 main device container width
2024-03-02 ui noodle, import/export settings framework
2024-03-03 use bootstrap close button for modal
2024-03-03 style device ui
2024-03-04 fw tidy up getting ready
    [cc_list.xlsx]
2024-03-06 TIMER0 = 1KHz w/irq
2024-03-06 dark mode transition time
    remove v-on for @ in device
2024-03-06 a big delete
    [473461001.sldprt, board.SLDPRT, bottom.SLDPRT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]
2024-03-06 store button style tracks changed config
    move modal up a bit
2024-03-07 scary rework of whole config thing
    [main.c]
2024-03-10 cc lsb tied to msb
    toggle uses slots for text
2024-03-10 swap info/darkmode buttons
2024-03-10 collapsible device ui
2024-03-11 add TX to original gadget pcb
    [wch554e.PcbLib, wch554e.SchLib, wch554g.PcbDoc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]
2024-03-11 multiple devices v1
    firmware version in device_id_response
    fix midi callbacks so they're per-device
    put serial # in device name
    [main.c, main.h]
2024-03-11 rearrange button ui
2024-03-11 device_type passed through makefile
2024-03-11 acceleration no longer embedded in flags
    [main.c]
2024-03-11 device type fw in separate folders
2024-03-11 device label stored in cookie
2024-03-12 save device label on blur (and blur on key_enter)
2024-03-16 printf, desc tables, device_direct
2024-03-16 custom hid device on endpoint 3
2024-03-17 tidy up led flash/tick
2024-03-21 modifiers, prepare for button ui
2024-03-21 ditch button release/momentary nonsense
2024-03-21 hard code reverse encoder for devkit
    [encoder.c]
2024-03-21 fix hid device cookie name
2024-03-21 device list stored differently
2024-03-22 fix device name
2024-03-22 hold button at startup to go to bootloader
2024-03-23 monitor hid device disconnect
2024-03-23 fix up intellisense in vs code
    [gpio_drv.h, main.h]
2024-03-23 fix midi build after intellisense nonsense
    [main.h]
2024-03-24 localStorage not cookies for device name
2024-03-24 handle midi device reconnection (kinda, dodgy af)
2024-03-24 remove orders.xlsx
    [orders.xlsx]
2024-03-29 encoder direction fix for original
    [encoder.c, gpio_drv.h]
2024-03-29 fix endpoints for midi
    [main.c]
2024-06-04 enclosure improve tabs
    [lower.SLDPRT, upper.SLDPRT]
2024-07-27 remove capacitors from switches
    [wch554g.PcbDoc, wch554g.SchDoc]
2024-10-07 add midi docs
    [enclosure.SLDDRW]
2024-10-18 add ch554e device type firmware
2024-10-18 checkpoint pcb before ch554e experiment
    [ch554_panel.PcbDoc, volume_knob.SchDoc, wch554e.SchLib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]
2024-10-28 firmware for pcb_v2
2024-10-28 enclosure_v2 wip
    [rotary_encoder_1.step.SLDPRT, upper.SLDPRT]
2025-02-15 bin files, docs, fw
    [enclosure_V2.SLDDRW, enclosure_V2_lower.STEP, enclosure_V2_upper.STEP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]
2026-02-22 add mouse support update pcb panel
    [Bill of Materials-wch554g.xlsx, Pick Place for ch554_panel.csv, TUVK_Enclosure.step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]
2026-03-10 fix device name descriptor length
2026-05-18 add demo devices
